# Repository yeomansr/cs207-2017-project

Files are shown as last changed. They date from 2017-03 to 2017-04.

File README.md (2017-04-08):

# Cyborg Headpiece (cs207-2017-project) [Version 1.3.3]
License:  [*Unlicense*](http://unlicense.org)

This is the repository for Richard Yeomans' CS 207 Project.

A cyborg headpiece, by my definition, is a piece of wearable technology affixed to the head of the wearer.  While I had originally intended to make the headpiece look as though it was integrated into the flesh of the wearer, I did not have enough time to finish it to this level of detail.

This class project has evolved a great deal from what I had originally intended.  At the beginning of the class, I did not really understand enough about what I would be able to do.  Now that the class is pretty well completed, this is the result of my work.

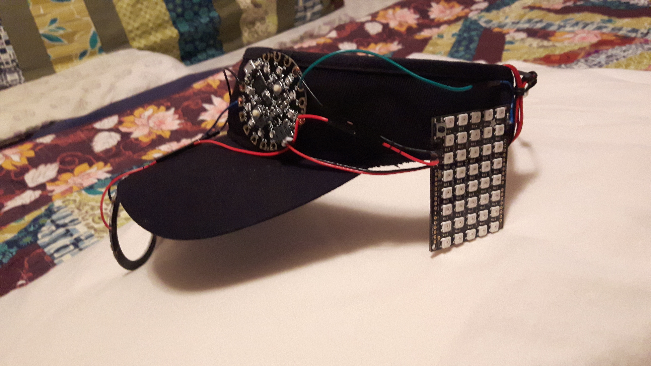
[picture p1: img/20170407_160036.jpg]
Cyborg Headpiece


[pic1]: https://github.com/yeomansr/cs207-2017-project/blob/master/img/20170407_160036.jpg "Cyborg Headpiece"

## Manifest
- **/doc** - technical documents (mostly PDF files)
- **/img** - image files (including Fritzing circuit diagrams)
- **/src** - source code file (.ino)
- **/LICENSE** - Unlicense file
- **/README.md** - this file

## Requirements and Materials
The following constitutes the materials I used in this project.  Many of these materials can be replaced with other similar materials as appropriate.
### Dependencies
- [add support for Adafruit to Arduino IDE](https://learn.adafruit.com/introducing-circuit-playground/arduino-1-dot-6-x-ide)
- [Adafruit NeoPixel Library](https://github.com/adafruit/Adafruit_NeoPixel) (not used, but helpful)

### Bill of Materials
- 1x [Adafruit Circuit Playground - Developer Edition](https://www.adafruit.com/products/3000)
- 1x [Adafruit NeoPixel Ring - 24 x 5050 RGB LED](https://www.adafruit.com/products/1586)
- 1x [Adafruit NeoPixel Shield for Arduino - 40 RGB LED Pixel Matrix](https://www.adafruit.com/products/1430)
- 1x [Adafruit USB cable - A/MicroB - 3ft](https://www.adafruit.com/product/592)
- 1x plain black visor
- 1x [Adafruit Premium Male/Male Jumper Wires - 40 x 6" (150mm)](https://www.adafruit.com/products/758)
- 1x [Adafruit Premium Female/Female Jumper Wires - 40 x 6"](https://www.adafruit.com/products/266)
- 1x [Adafruit JST-PH Battery Extension Cable - 500mm](https://www.adafruit.com/products/1131)
- 1x [Adafruit 3 x AAA Battery Holder with On/Off Switch and 2-Pin JST](https://www.adafruit.com/products/727)
- 3x Alkaline AAA batteries
- 1x [Adafruit Needle set - 3/9 sizes - 20 needles](https://www.adafruit.com/products/615)
- black thread
- clear nail polish
- black electrical tape
- wire cutters
- wire strippers

## Build Instructions
Ultimately, the components will be connected as per the following diagrams:

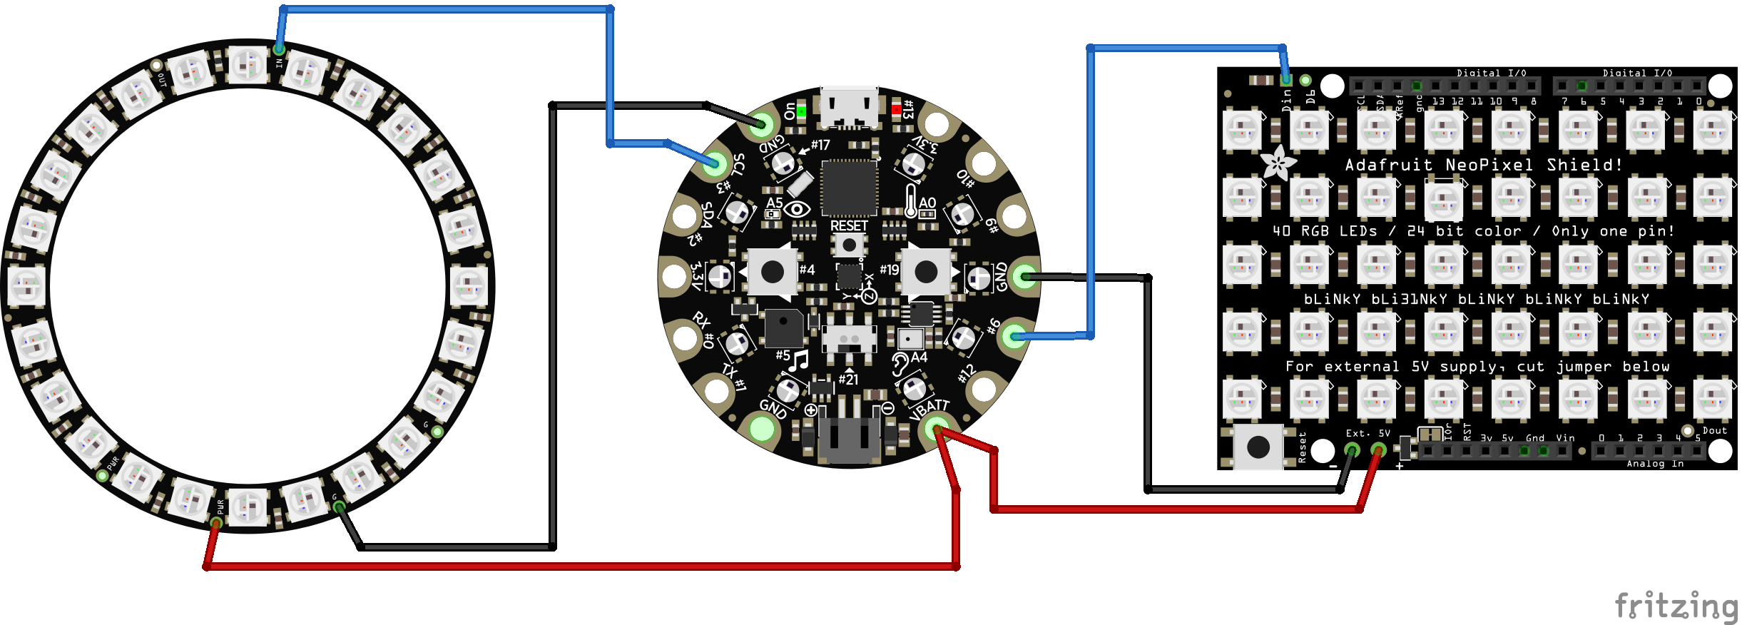
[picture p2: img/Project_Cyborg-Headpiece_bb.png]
Fritzing Diagram 1


[pic2]: https://github.com/yeomansr/cs207-2017-project/blob/master/img/Project_Cyborg-Headpiece_bb.png "Fritzing Diagram 1"

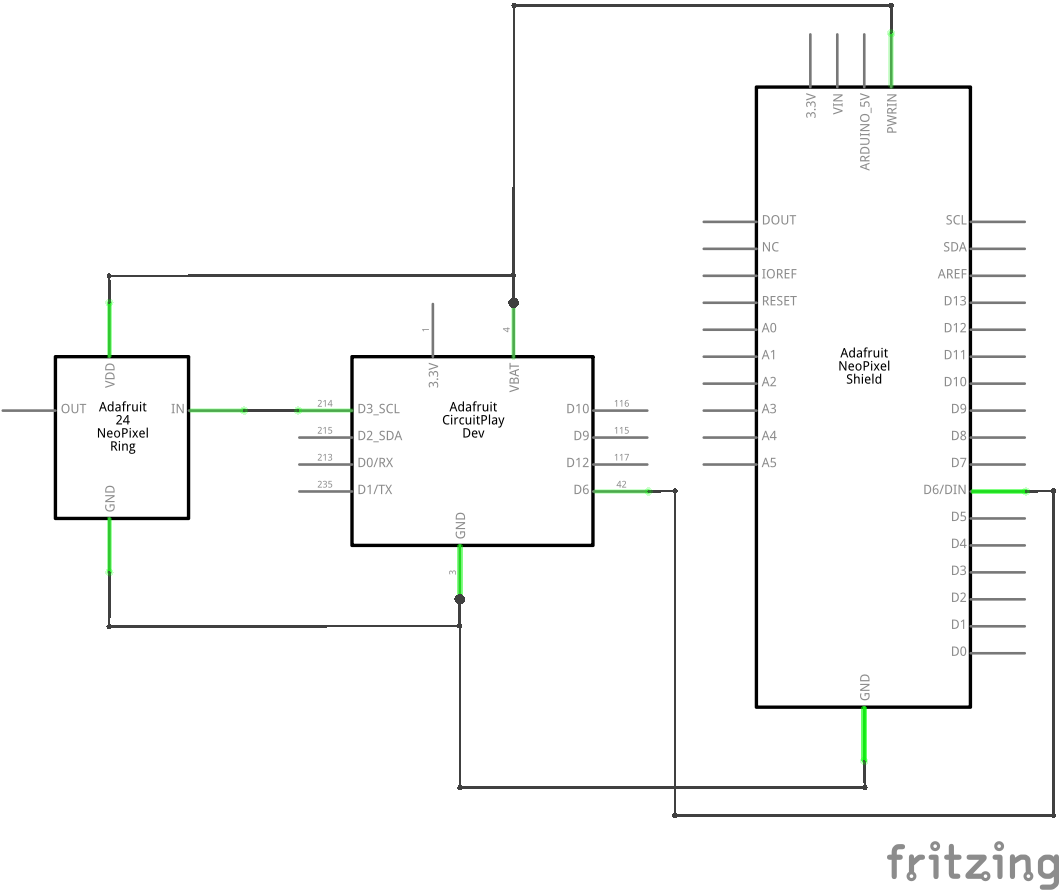
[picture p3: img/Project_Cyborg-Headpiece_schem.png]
Fritzing Diagram 2


[pic3]: https://github.com/yeomansr/cs207-2017-project/blob/master/img/Project_Cyborg-Headpiece_schem.png "Fritzing Diagram 2"

First, prepare the NeoPixel Shield and NeoPixel Ring by attaching some wires to the appropriate connectors:
1. Pull the Male/Male Jumper Wires apart, so that you are working with individual wires.
2. Take a black wire and cut it in half.
3. Strip about 3 cm off the wire end off both pieces (maintain the connector ends)
4. Wrap the stripped end of one of the wire pieces to the connector labeled *Ext.* on the NeoPixel Shield.  Continue wrapping it around several times.
5. Wrap the stripped end of one of the wire pieces to the connector labeled *GND* on the NeoPixel Ring.  Continue wrapping it around several times.
6. Place a dab of nail polish onto the front and back of both connectors, to seal the wires to the connectors.
7. Allow the nail polish to dry.
8. Trim any excess wire from the connectors, and make them neat.  Ensure you don't create any shorts while doing this.
9. Repeat steps 2 to 8, this time using a red wire, and connecting to *5V* on the NeoPixel Shield, and connecting to *PWR +5V* on the NeoPixel Ring.
10. Repeat steps 2 to 8, this time using a blue wire, and connecting to *Din* on the NeoPixel Shield, and connecting to *Data Input* on the NeoPixel Ring.

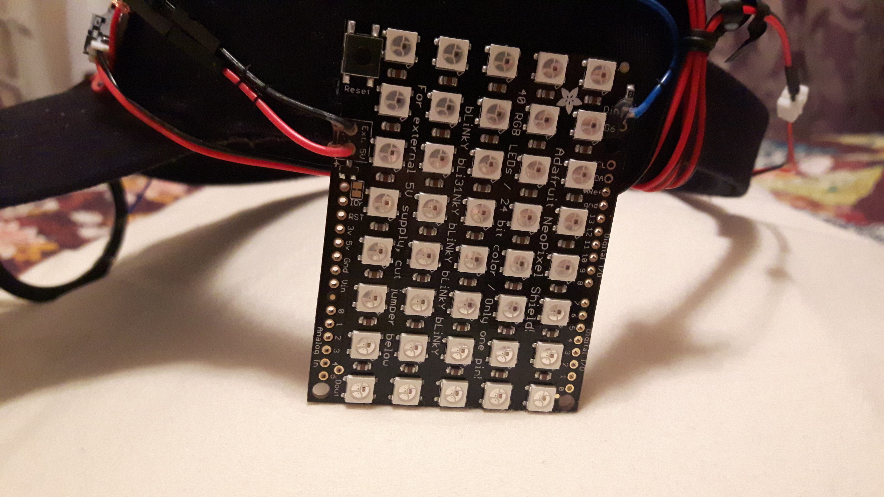
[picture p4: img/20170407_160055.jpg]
NeoPixel Shield


[pic4]: https://github.com/yeomansr/cs207-2017-project/blob/master/img/20170407_160055.jpg "NeoPixel Shield"

Attach the NeoPixel Shield and NeoPixel Ring to the visor using the black thread.  Simply sew the thread through any unused connector holes in the NeoPixel Shield to the side of the visor, allowing the end where the wires are not attached hang down.  When wearing the visor, the NeoPixel Shield should hang roughly over one of the wearer's ears.

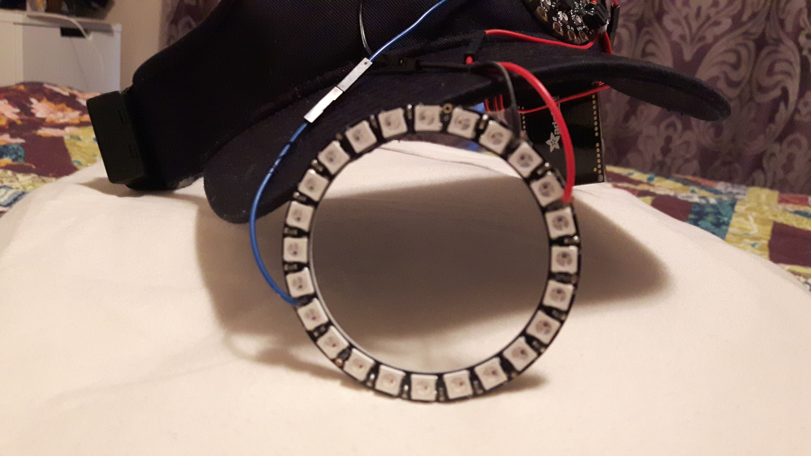
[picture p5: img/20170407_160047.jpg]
NeoPixel Ring


[pic5]: https://github.com/yeomansr/cs207-2017-project/blob/master/img/20170407_160047.jpg "NeoPixel Ring"

To attach the NeoPixel Ring, simply sew thread around the ring, between the NeoPixels to the end of the visor.  It will be loose to begin with, but as you sew more loops of thread to the visor, it will stabalize.  Ensure the wires are going up and over the visor.  Place the ring approximately in front of one of the wearer's eyes, sort of like a monocle.

Hold the Circuit Playground against the visor in an appropriate place between the NeoPixel Shield and NeoPixel Ring.  It isn't critical it be in any exact place, but you will want to hold it in place to identify how long the wires will need to be to connect to both the NeoPixel Shield and NeoPixel Ring.
1. Pull the Female/Female Jumper Wires apart, so that you are working with individual wires.
2. Repeat steps 2 to 8 above, this time using the Female/Female wire pieces.  Cut them to appropriate lengths based on the position of the components.  Make the wire pieces a little longer than you need, so that the wires are not too tight when connected.
  - For connections to the NeoPixel Shield: black wire to *GND*, red wire to *VBATT*, blue wire to *Pin #6*
  - For connections to the NeoPixel Ring: black wire to *GND*, red wire to *VBATT*, blue wire to *Pin #3*

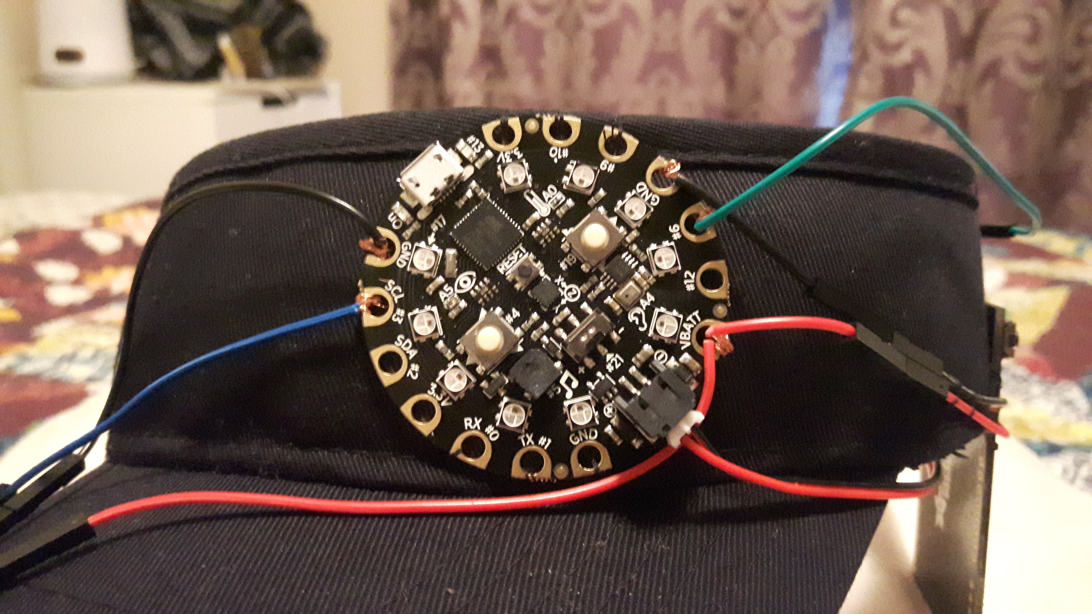
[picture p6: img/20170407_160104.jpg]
Circuit Playground


[pic6]: https://github.com/yeomansr/cs207-2017-project/blob/master/img/20170407_160104.jpg "Circuit Playground"

Sew the Circuit Playground to the visor in the same place you picked earlier.  Once it is secured to the visor, you may now connect the male and female ends of the wires to establish the connections between the Circuit Playground and the NeoPixel Shield and NeoPixel Ring.

Put batteries into the Battery Holder.  Find an appropriate place to attach the Battery Holder; use the electrical tape to attach it.  If the connector for the Battery Holder is too far from the Circuit Playground to connect, make use of the Battery Extension Cable, as I did.

Use black thread as appropriate to hold the wires nicely to the visor.

## Firmware Installation
In order to upload the code to the Circuit Playground, you will need to first install the Arduino IDE software.  Follow the instructions on Adafruit's website: *Arduino 1.6.x IDE* in the references.  Don't forget to add the *Adafruit Board Support* package, further down on the page.

Connect the Circuit Playground using the USB cable.  Load the code *sketch_project.ino* that can be found in the *src* directory.

## Usage
The Battery Holder has a power switch on it; use this switch to turn on or off the headpiece.

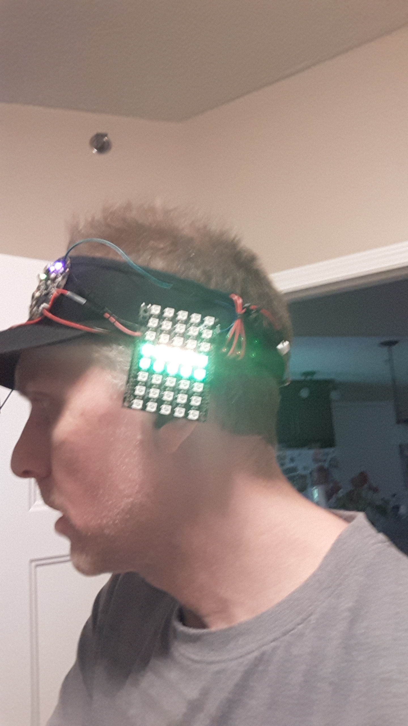
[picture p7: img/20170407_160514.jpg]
Sound Reactor


[pic7]: https://github.com/yeomansr/cs207-2017-project/blob/master/img/20170407_160514.jpg "Sound Reactor"

The NeoPixel Shield responds to sounds.  Talk or otherwise make some noises and you will see the NeoPixel Shield light up.

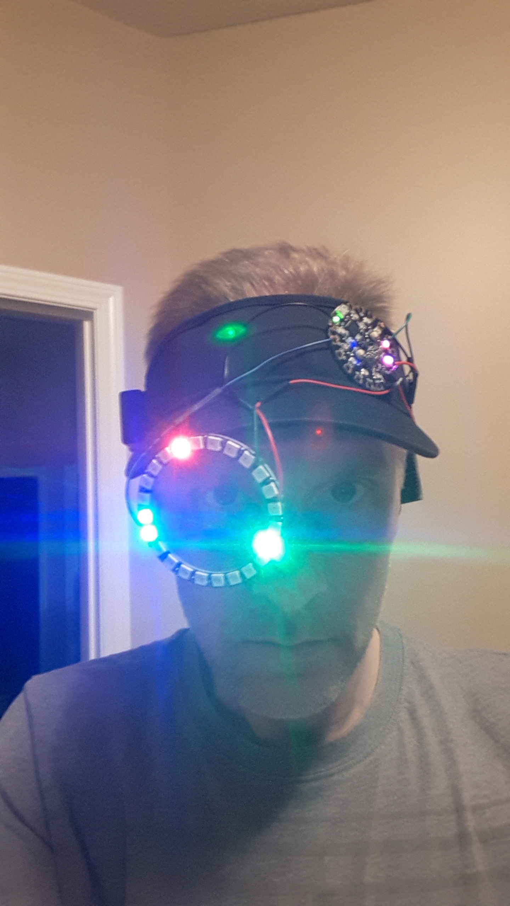
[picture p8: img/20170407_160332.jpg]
Orientation Reactor


[pic8]: https://github.com/yeomansr/cs207-2017-project/blob/master/img/20170407_160332.jpg "Orientation Reactor"

The NeoPixel Ring responds to the visor's orientation.  The 3 dots will rotate around the ring based on the X, Y, and Z orientations of the Circuit Playground.  Move it around to see the effects.

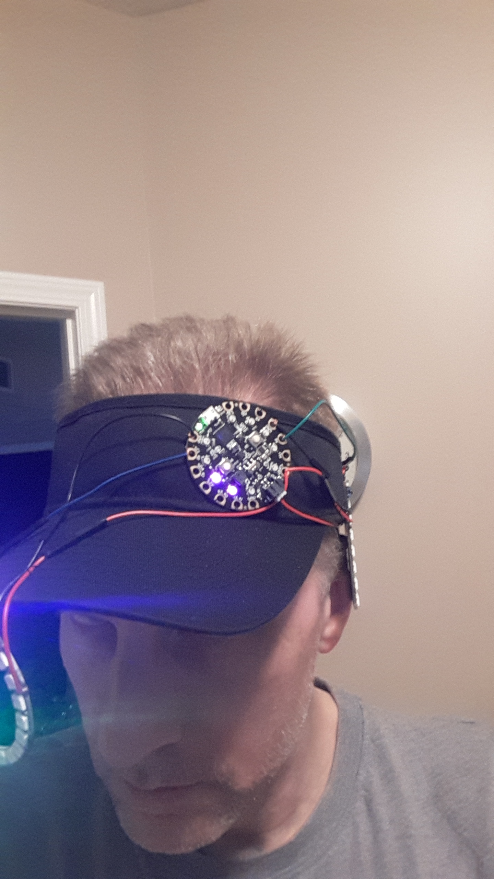
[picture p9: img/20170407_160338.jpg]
Basic Operation


[pic9]: https://github.com/yeomansr/cs207-2017-project/blob/master/img/20170407_160338.jpg "Basic Operation"

The Circuit Playground has some NeoPixels on it as well.  The dot will go around it to indicate that there is stuff going on.  Both buttons can be pressed and will change the behavior of the Circuit Playground dot.  Furthermore, the switch on the Circuit Playground will freeze all responses on all components when switched.

## Team
The project team consists of:
- [Richard Yeomans](mailto:yeomansr@uregina.ca)

It's a small team.

## Acknowledgements
### Credits
- Robin Canham - her assistance and support was invaluable
- Trevor Tomesh - CS 207 class instructor, provided insight and assistance all over the place

### References
- *Arduino 1.6.x IDE | Introducing Circuit Playground | Adafruit Learning System*.  (2017).  *Learn.adafruit.com*.  Retrieved 8 April 2017, from [https://learn.adafruit.com/introducing-circuit-playground/arduino-1-dot-6-x-ide](https://learn.adafruit.com/introducing-circuit-playground/arduino-1-dot-6-x-ide)
- *adafruit/Fritzing-Library*.  (2017).  *GitHub*.  Retrieved 8 April 2017, from [https://github.com/adafruit/Fritzing-Library](https://github.com/adafruit/Fritzing-Library)
- *Downloads | Introducing Circuit Playground | Adafruit Learning System*.  (2017).  *Learn.adafruit.com*.  Retrieved 19 March 2017, from [https://learn.adafruit.com/introducing-circuit-playground/downloads](https://learn.adafruit.com/introducing-circuit-playground/downloads)
- *Mastering Markdown · GitHub Guides*.  (2017).  *Guides.github.com*.  Retrieved 5 February 2017, from [https://guides.github.com/features/mastering-markdown/](https://guides.github.com/features/mastering-markdown/)
- Stern, B. & Burgess, P.  (2017).  *Cyberpunk Spikes | Make:. Make: DIY Projects and Ideas for Makers*.  Retrieved 5 February 2017, from [http://makezine.com/projects/make-42/cyberpunk-spikes/](http://makezine.com/projects/make-42/cyberpunk-spikes/)
- *The Magic of NeoPixels | Adafruit NeoPixel Überguide | Adafruit Learning System*.  (2017).  *Learn.adafruit.com*.  Retrieved 25 March 2017, from [https://learn.adafruit.com/adafruit-neopixel-uberguide/overview](https://learn.adafruit.com/adafruit-neopixel-uberguide/overview)
- Tomesh, T.  (2017).  *trevortomesh/OSHRepo*.  *GitHub*.  Retrieved 5 February 2017, from [https://github.com/trevortomesh/OSHRepo](https://github.com/trevortomesh/OSHRepo)

## Version History
version 1.3.3
- fixing formatting errors in README

version 1.3.2
- added pictures and diagrams

version 1.3.1
- fixing formatting errors in README

version 1.3.0
- updated description
- updated Manifest
- updated Requirements and Materials
- added Build Instructions
- added Firmware Installation
- added Usage
- added reference to Arduino 1.6.x IDE
- added reference to Adafruit Fritzing Library

version 1.2.0
- added reference to NeoPixel guide

version 1.1.5
- fixing formatting errors in README

version 1.1.4
- fixing formatting errors in README

version 1.1.3
- added reference to Adafruit downloads for Circuit Playground

version 1.1.2
- added manufacturer information to materials

version 1.1.1
- fixing formatting errors in README

version 1.1.0
- updates to bill of materials

version 1.0.3
- added important reference

version 1.0.2
- fixing formatting errors in README

version 1.0.1
- fixing formatting errors in README

version 1.0.0
- starting project

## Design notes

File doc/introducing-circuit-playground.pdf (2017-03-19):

### Introducing Circuit Playground

Created by lady ada

Last updated on 2017-02-08 04:37:44 PM UTC

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
## Guide Contents

Guide Contents Overview Pinouts GPIO + Capacitive Touch Pads NeoPixels Pushbuttons Slide Switch Light Sensor Temperature Sensor Speaker Buzzer Microphone Audio Sensor Triple-Axis Accelerometer Windows Driver Installation Manual Driver Installation Arduino 1.6.x IDE Super Easy Installation (Recommended)

Add the Adafruit Board Support package!
Manage Board Support

### All-in-one Installation (not recommended!) Manual Installation (super advanced!) HELP! Libraries Installing Via Library Manager Download Adafruit_CircuitPlayground 'Manually' Run the Demo

Select the Circuit Playground Board
Select the matching Port
Load the Demo Program
Compile/Verify the Demo
Upload Demo

### Downloads Windows Driver Software

© Adafruit Industries | https://learn.adafruit.com/introducing-circuit-playground | Page 2 of 37

35
35
35
36

### Source Datasheets Schematic Fabrication Print

© Adafruit Industries | https://learn.adafruit.com/introducing-circuit-playground | Page 3 of 37

# Overview

Would you like to learn electronics, with an all-in-one board that has sensors and LEDs built in? Circuit Playground is here, and it's the best way to practice programming on real hardware. No soldering or sewing required!

Circuit Playground features an ATmega32u4 micro-processor, just like our popular Flora. It also is round and has alligator-clip pads around it. You can power it from USB, a AAA battery pack (http://adafru.it/727), or Lipoly (for advanced users). Program your code (https://www.adafruit.com/products/727) into it, then take it on the go.

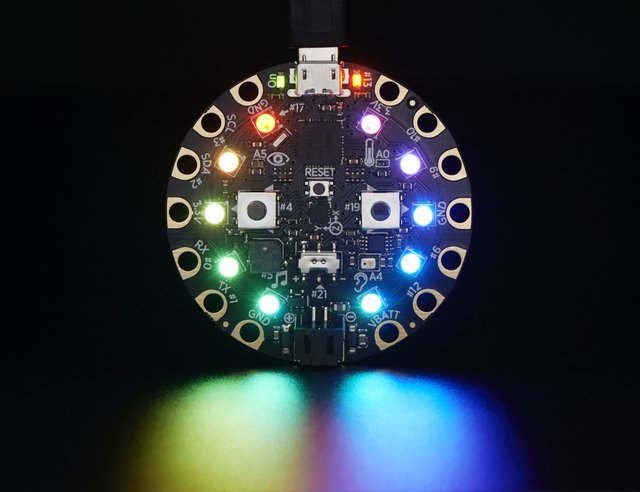
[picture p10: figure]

ATmega32u4 Processor, running at 3.3V and 8MHz
MicroUSB port for programming and debugging with Arduino IDE
USB port can act like serial port, keyboard, mouse, joystick or MIDI
© Adafruit Industries | https://learn.adafruit.com/introducing-circuit-playground | Page 4 of 37

Circuit Playground has built-in USB support. Built in USB means you plug it in to program it, it just shows up - all you need is a Micro-B USB cable, no additional purchases are needed! With the new 1.6.4+ Arduino IDE, it takes only a few seconds to add
support (http://adafru.it/nb4). The Circuit Playground has USB HID support, so it can act like a mouse or keyboard to attach directly to computers.

Here's some of the great goodies baked in:

10 x mini NeoPixels, each one can display any rainbow color
1 x Motion sensor (LIS3DH triple-axis accelerometer with tap detection, free-fall detection)
1 x Temperature sensor (thermistor)
1 x Light sensor (phototransistor)
1 x Sound sensor (MEMS microphone) 1 x Mini speaker (magnetic buzzer)
2 x Push buttons, left and right
1 x Slide switch
8 x alligator-clip friendly input/output pins
© Adafruit Industries | https://learn.adafruit.com/introducing-circuit-playground | Page 5 of 37

Includes I2C, UART, and 4 pins that can do analog inputs/PWM output All 8 pads can act as capacitive touch inputs
Green "ON" LED so you know its powered
Red "#13" LED for basic blinking
Reset button

We've started out with aDeveloper Edition of Circuit Playground. This version is designed for people who have a little experience with Arduino already, who want to help build & document projects. There might be minor hardware or software bugs. Once we feel like the design is really solid we'll revise/re-release it into a universal edition for anyone to use!

© Adafruit Industries | https://learn.adafruit.com/introducing-circuit-playground | Page 6 of 37

# Pinouts

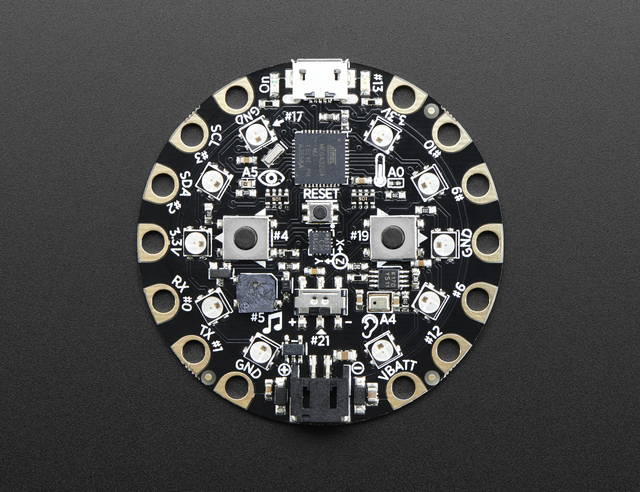
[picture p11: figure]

Circuit Playground is chock-full of blinkies, sensors and electronic goodies. Since there's a lot going on, we're going to look at each piece one by one and talk about what it is and how to use it. This is a technically-oriented description for the Developer Edition and the people who are planning on writing code for Circuit Playground

# GPIO + Capacitive Touch Pads

© Adafruit Industries | https://learn.adafruit.com/introducing-circuit-playground | Page 7 of 37

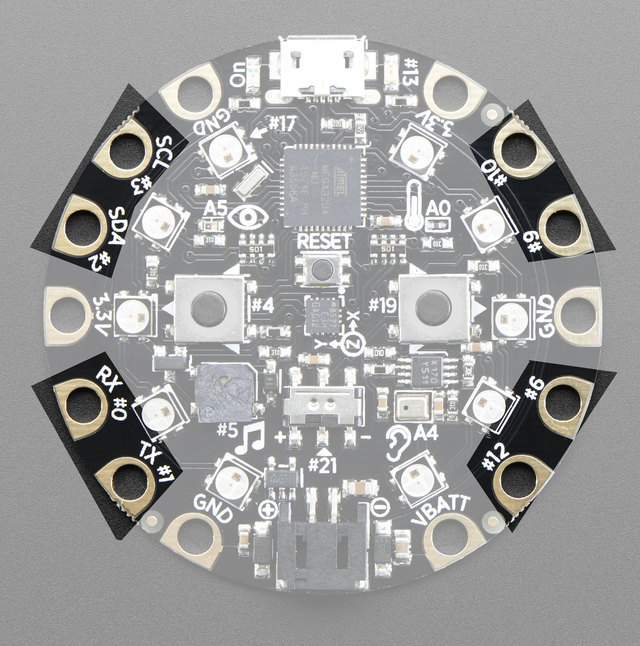
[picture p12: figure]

All 8 non-power pads around the circuit playground have the ability to act as capacitive touch pads. Each pad has a 1Mohm resistor between it and digital pin #30. You can toggle this pin to control whether the resistor is a pullup or pulldown or floating. Note that this means that all the pads have a 2Mohm resistance between them.

You can also of course just use those pads for GPIO, we expose the hardware Serial (TX + RX), hardware I2C (SDA + SCL) and 4 gpio pins that can also do analog readings. They are the same exact pins as those on the Flora

© Adafruit Industries | https://learn.adafruit.com/introducing-circuit-playground | Page 8 of 37

# NeoPixels

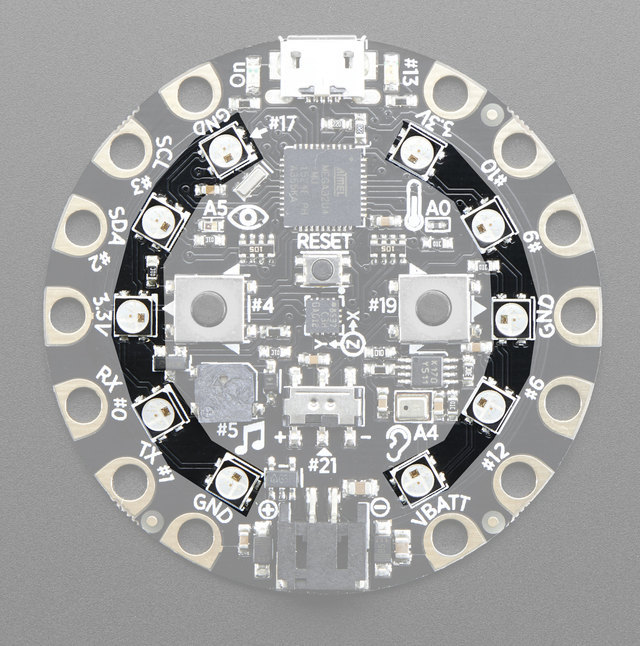
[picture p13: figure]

Each Circuit Playground comes with 10 'NeoPixels' (technically, SK6812-3535 chips). These are connected to digital pin #17 and are powered by the 3.3V regulator. This is technically undervolting but we test them at this voltage and they work fine, if slightly tinted

# Pushbuttons

© Adafruit Industries | https://learn.adafruit.com/introducing-circuit-playground | Page 9 of 37

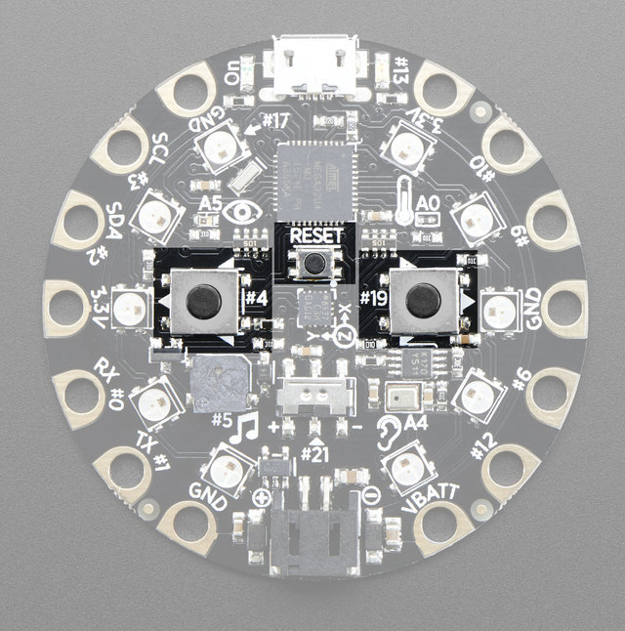
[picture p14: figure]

There are three tactile pushbutton switches. One is the Reset button. Press this button once to reset, double-click to enter the bootloader manually.

The other two buttons are the Left and Right buttons, connected to digital#4 (Left) and #19 (Right) each. These have pull-down resistors installed so are, by default, LOW and when pressed read HIGH. This is to make if-then logic a little easier to read for beginners

# Slide Switch

© Adafruit Industries | https://learn.adafruit.com/introducing-circuit-playground | Page 10 of 37

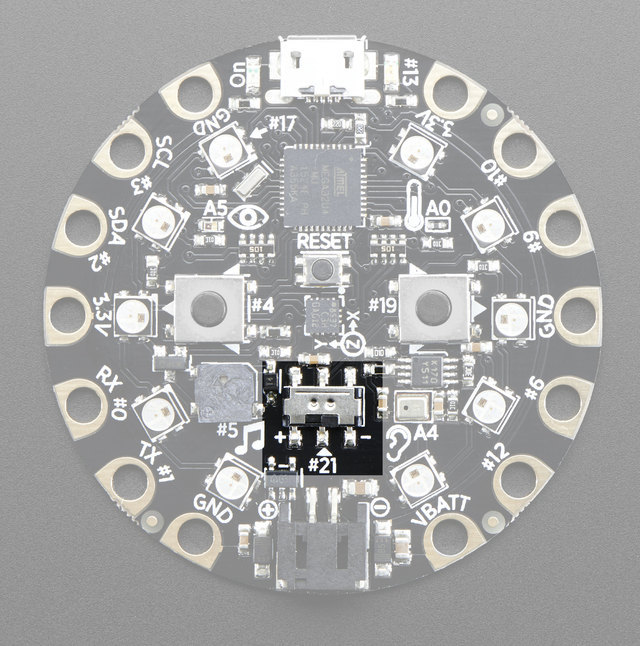
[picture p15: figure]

There is a single slide switch near the center of the Circuit Playground. It is connected to digital #21 and will read LOW when slid to the left, and HIGH when in the right hand position

# Light Sensor

© Adafruit Industries | https://learn.adafruit.com/introducing-circuit-playground | Page 11 of 37

There is an analog light sensor,part number ALS-PT19 (http://adafru.it/tC2), in the top left part of the board. This can be used to detect ambient light, with similar spectral response to the human eye.

This sensor is connect to analog pin #A5 and will read between 0 and 1023 with higher values corresponding to higher light levels. A reading of about 300 is common for most indoor light levels.

# Temperature Sensor

© Adafruit Industries | https://learn.adafruit.com/introducing-circuit-playground | Page 12 of 37

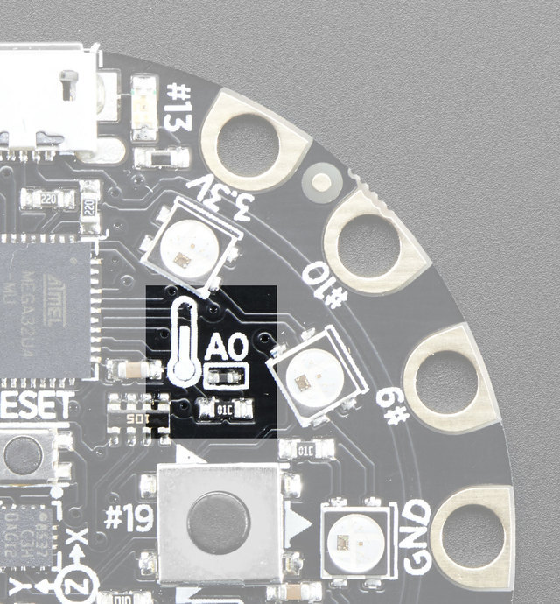
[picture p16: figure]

There is an NTC thermistor (Murata NCP15XH103F03RC) that we use for temperature sensing. While it isn't an all-in-one temperature sensor, with linear output, it's easy to calculate the temperature based on the analog voltage on analog pin #A0. There's a 10K resistor connected to it as a pull down.

# Speaker Buzzer

© Adafruit Industries | https://learn.adafruit.com/introducing-circuit-playground | Page 13 of 37

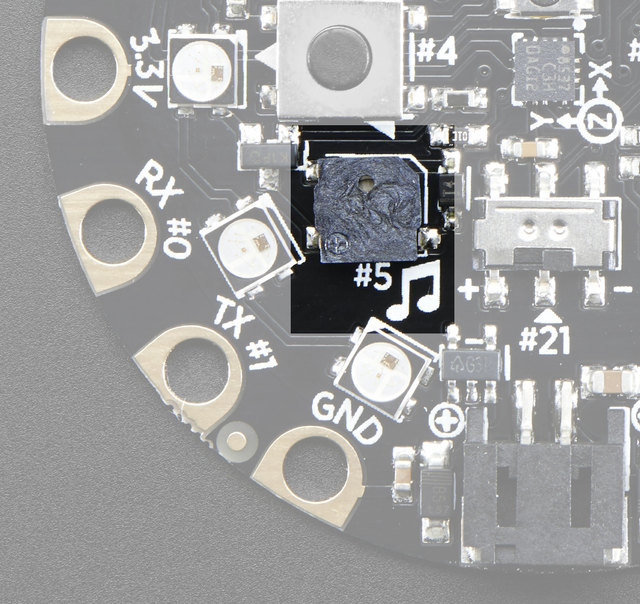
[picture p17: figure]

You can make your circuit playground sing with the built in buzzer. This is a miniature magnetic speaker connected to digital pin #5 with a transistor driver. You can use PWM at varying frequencies to make basic tones.

# Microphone Audio Sensor

© Adafruit Industries | https://learn.adafruit.com/introducing-circuit-playground | Page 14 of 37

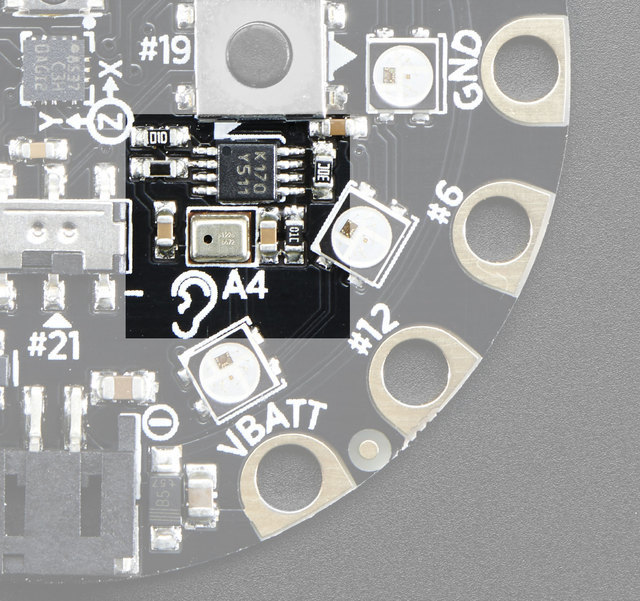
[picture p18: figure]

A MEMS microphone can be used to detect audio levels and even perform basic FFT functions. You can read the analog voltage corresponding to the audio on analog pin #A4. Note that this is the raw analog audio waveform! When it's silent there will be a reading of ~330 and when loud the audio will read between 0 and 800 or so. Averaging and smoothing must be done to convert this to sound-pressure-level.

# Triple-Axis Accelerometer

© Adafruit Industries | https://learn.adafruit.com/introducing-circuit-playground | Page 15 of 37

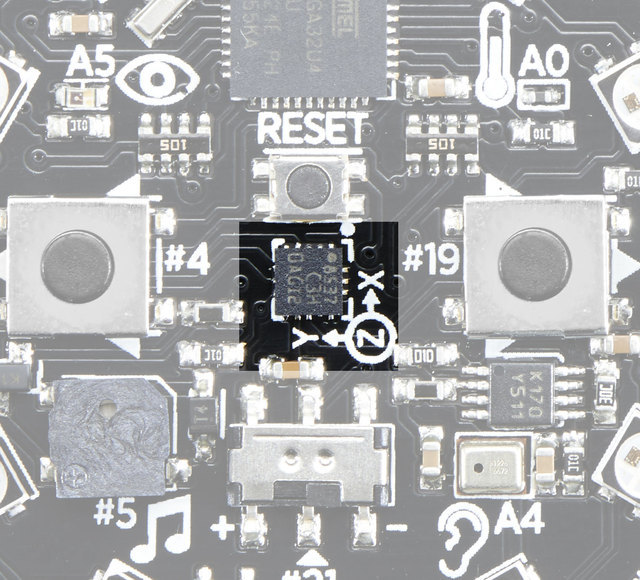
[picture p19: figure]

A LIS3DH 3-axis XYZ accelerometer is in the dead center of the board and you can use it to detect tilt, gravity, motion, as well as 'tap' and 'double tap' strikes on the board. The LIS3DH is connected to the hardware SPI pins (to leave the I2C pins free) and has the CS pin on digital pin #8 and an optional interrupt output on digital pin#7 (also known as IRQ #4)

© Adafruit Industries | https://learn.adafruit.com/introducing-circuit-playground | Page 16 of 37

# Windows Driver Installation

Mac and Linux do not require drivers, only Windows folks need to do this step

Before you plug in your board, you'll need to possibly install a driver!

Click below to download our Driver Installer

Download Adafruit Windows Driver Installer (https://github.com/adafruit/Adafruit_Windows_Drivers/releases/download/1.0.0.0/adafruit_drivers.exe)
http://adafru.it/mai

Download and run the installer

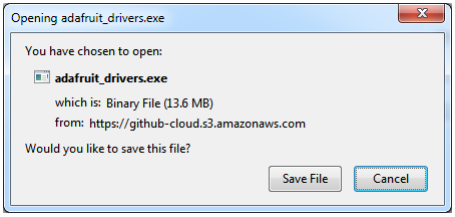
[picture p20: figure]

Run the installer! Since we bundle the SiLabs and FTDI drivers as well, you'll need to click through the license

© Adafruit Industries | https://learn.adafruit.com/introducing-circuit-playground | Page 17 of 37

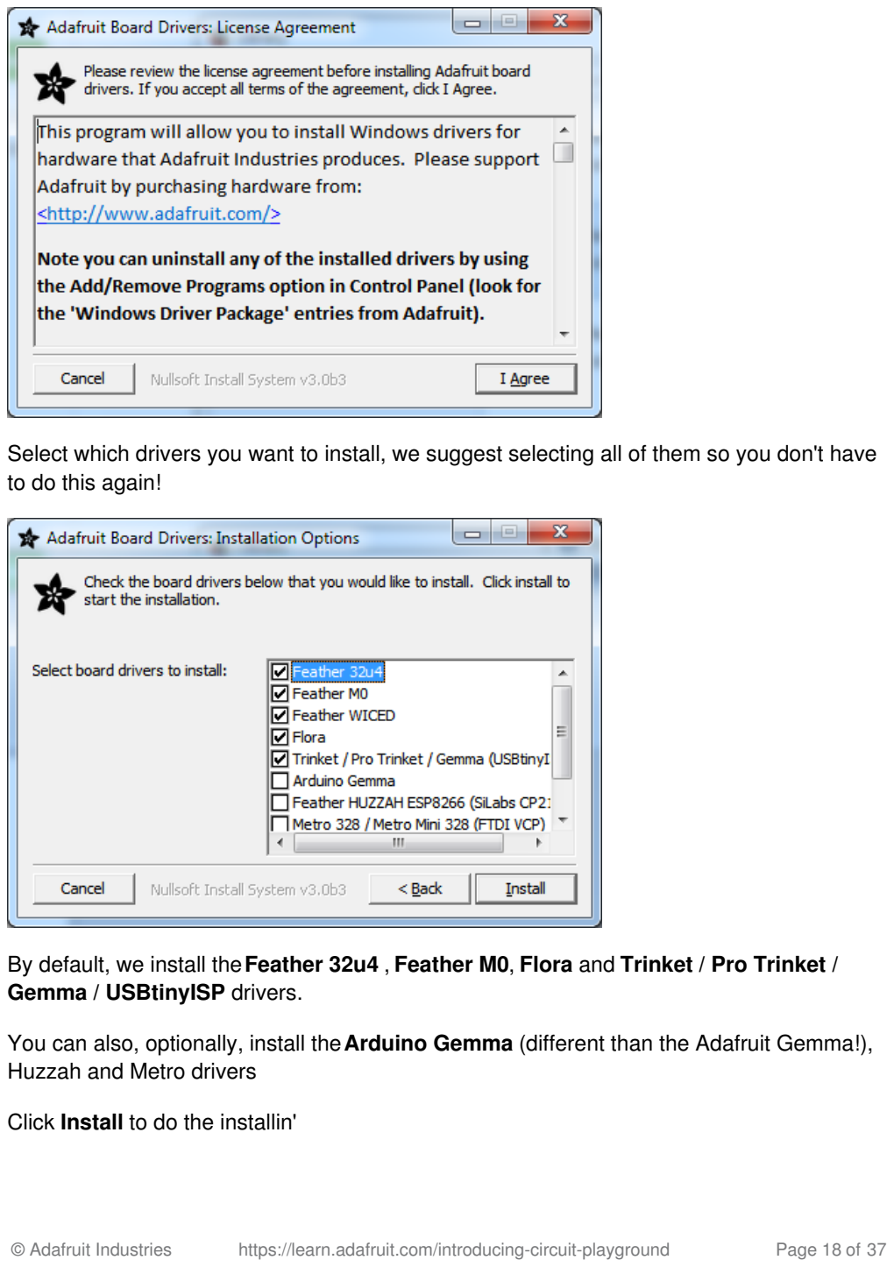
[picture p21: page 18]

Select which drivers you want to install, we suggest selecting all of them so you don't have to do this again!

By default, we install theFeather 32u4 , Feather M0, Flora and Trinket / Pro Trinket / Gemma / USBtinyISP drivers.

You can also, optionally, install theArduino Gemma (different than the Adafruit Gemma!), Huzzah and Metro drivers

Click Install to do the installin'

© Adafruit Industries | https://learn.adafruit.com/introducing-circuit-playground | Page 18 of 37

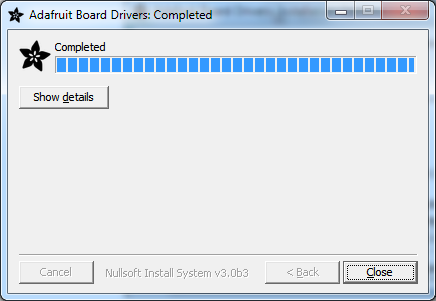
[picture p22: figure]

# Manual Driver Installation

If windows needs the driver files (inf/cat) for some reason you can get all the drivers in a zip by clicking below:

Adafruit Windows Drivers (https://github.com/adafruit/Adafruit_Windows_Drivers/archive/master.zip)
http://adafru.it/rEY

And point windows to theDrivers folder when it asks for the driver location

© Adafruit Industries | https://learn.adafruit.com/introducing-circuit-playground | Page 19 of 37

# Arduino 1.6.x IDE

The Arduino IDE version 1.6.x is the latest version of Arduino and recommended for most users. Follow the steps on this page to learn how to install a version of the Arduino 1.6.x IDE with support for Adafruit's boards.

# Super Easy Installation (Recommended)

With the Arduino IDE version 1.6.4 and greater you can now add 3rd party boards directly from the stock IDE! The first thing you will need to do is to download the latest release of the Arduino IDE. You will need to be using version 1.6.4 or higher:

Latest Arduino IDE Download (http://www.arduino.cc/en/Main/Software)
http://adafru.it/f1P

After you have downloaded and installed the latest version (remember itmust be 1.6.4 or higher), you will need to start the IDE and navigate to the Preferences menu. You can access it from the File menu in Windows or Linux, or the Arduino menu on OS X.

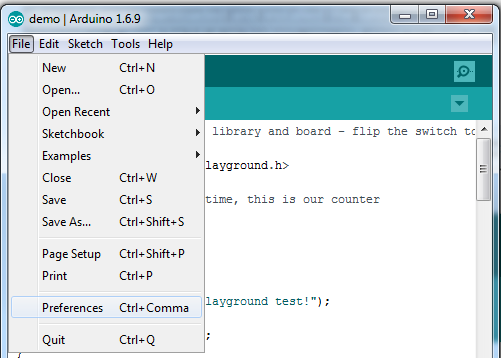
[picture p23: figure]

A dialog will pop up just like the one shown below.

© Adafruit Industries | https://learn.adafruit.com/introducing-circuit-playground | Page 20 of 37

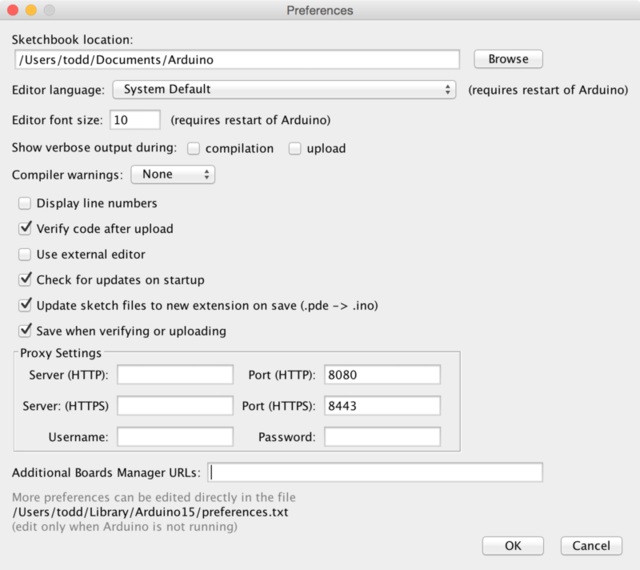
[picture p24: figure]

We will be adding a URL to the newAdditional Boards Manager URLs option. The list of URLs is comma separated, and you will only have to add each URL once.New Adafruit boards and updates to existing boards will automatically be picked up by the Board Manager each time it is opened. The URLs point to index files that the Board Manager uses to build the list of available & installed boards.

To find the most up to date list of URLs you can add, you can visit the list ofthird party board URLs on the Arduino IDE wiki (http://adafru.it/f7U). We will only need to add one (https://github.com/arduino/Arduino/wiki/Unofficial-list-of-3rd-party-boards-support-urls) URL to the IDE in this example, but you can add multiple URLS by separating them with commas. Copy and paste the link below into the Additional Boards Manager URLs option in the Arduino IDE preferences.

If you don't see the Additional Boards Manager URLs box, make sure you downloaded the Arduino IDE from arduino.cc! Older versions and derivatives of the IDE may not have it

© Adafruit Industries | https://learn.adafruit.com/introducing-circuit-playground | Page 21 of 37

## Add the Adafruit Board Support package!

Paste

https://adafruit.github.io/arduino-board-index/package_adafruit_index.json Into the "Additional Board Managers URLS" box

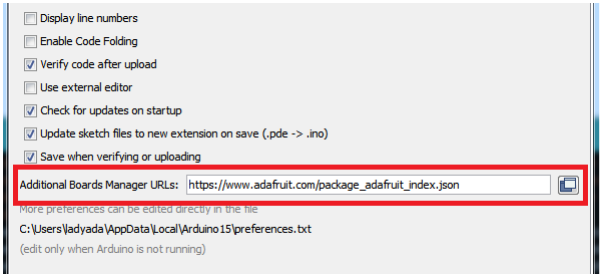
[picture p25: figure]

Click OK to save the new preference settings. Next we will look at installing boards with the Board Manager.

## Manage Board Support

Adding the link to the Adafruit board support package does not actually install anything, it only tells the Arduino IDE where to find the software.

Now that you have added the appropriate URLs to the Arduino IDE preferences, you can open the Boards Manager by navigating to theTools->Board menu.

Once the Board Manager opens, click on the category drop down menu on the top left hand side of the window and select Contributed. You will then be able to select and install the boards supplied by the URLs added to the prefrences. In the example below, we are installing support for Adafruit AVR Boards, but the same applies to all boards installed with the Board Manager.

© Adafruit Industries | https://learn.adafruit.com/introducing-circuit-playground | Page 22 of 37

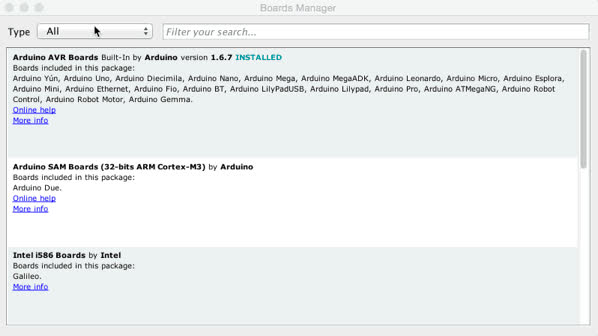
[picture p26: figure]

Next, quit and reopen the Arduino IDEto ensure that all of the boards are properly installed. You should now be able to see the new boards listed in the Tools->Board menu.

Finally follow the steps below for your platform to finish the installation - basically installing drivers and permissions management

Windows Setup (http://adafru.it/jAa)
Mac OSX Setup (http://adafru.it/mak)
Linux Setup (http://adafru.it/iOE)

Also check out the troubleshooting section (http://adafru.it/mal) for some advice on common errors. Have fun using Adafruit's boards!

# All-in-one Installation (not recommended!)

If you have trouble using the super easy installation method above another way to install support for Adafruit's boards is with the following preconfigured Arduino IDE downloads. It isn't recommended because you wont have the latest IDE!

Just grab the right file for your platform and use it like the normal Arduino IDE. Adafruit's boards like Trinket, Pro Trinket, Gemma, and Flora are configured to show up in the board list automatically

Arduino 1.6.4 with Adafruit Boards for Windows (https://s3.amazonaws.com/adafruit-download/adafruit-arduino-1.6.4-windows.zip)
http://adafru.it/f83
© Adafruit Industries | https://learn.adafruit.com/introducing-circuit-playground | Page 23 of 37

Arduino 1.6.4 with Adafruit Boards for Mac OSX (10.7+) (https://s3.amazonaws.com/adafruit-download/adafruit-arduino-1.6.4-macosx.zip) http://adafru.it/f84
Arduino 1.6.4 with Adafruit Boards for Linux (32-bit) (https://s3.amazonaws.com/adafruit-download/adafruit-arduino-1.6.4-linux32.tar.xz) http://adafru.it/f85
Arduino 1.6.4 with Adafruit Boards for Linux (64-bit) (https://s3.amazonaws.com/adafruit-download/adafruit-arduino-1.6.4-linux64.tar.xz)
http://adafru.it/f86

Once you've downloaded and installed the IDE follow the steps below for your platform to finish the installation:

Windows Setup (http://adafru.it/jAa)
Mac OSX Setup (http://adafru.it/mak)
Linux Setup (http://adafru.it/iOE)

Also check out the troubleshooting section (http://adafru.it/mal) for some advice on common errors. Have fun using Adafruit's boards!

# Manual Installation (super advanced!)

If you have your own version of the Arduino IDE or would like to install the Adafruit boards yourself then follow the steps below. However it is highly recommended that most users stick to the initial methods

With the 1.6.x version of the Arduino IDE the process of adding support for new boards is much simpler than previous versions. First start by downloading a version of the Arduino 1.6.x IDE and installing it as normal. Note that these instructions are only tested to work against the Arduino 1.6.4 IDE, earlier or later versions may or may not work!

Once you've installed the stock Arduino IDE download and unzip the following file which contains Adafruit's board definitions (https://github.com/adafruit/Adafruit_Arduino_Boards) (http://adafru.it/eTY):

Adafruit Board Definitions (https://github.com/adafruit/Adafruit_Arduino_Boards/archive/master.zip)
http://adafru.it/eTZ

Unzip the file and navigate inside theAdafruit_Arduino_Boards folder to find a hardware subfolder with a small hiearchy of files, and adrivers folder with Flora drivers specific to Windows.

Next find your installed Arduino IDE's hardware subfolder. For Windows and Linux the hardware subfolder should be directly beneath the folder where Arduino's IDE was installed.

For Mac OSX the folder is hidden inside the application bundle. Right click on the Arduino

© Adafruit Industries | https://learn.adafruit.com/introducing-circuit-playground | Page 24 of 37

application and click 'Show Package Contents', then navigate to theContent -> Java -> Hardware folder to find the hardware subfolder.

Once you've found Arduino's hardware subfolder carefully merge in the contents of the hardware folder from Adafruit's board definitions, being sure to overwrite any file that conflicts (only avrdude.conf should conflict). When you're done the Arduino hardware folder should have the following hiearchy:

hardware
adafruit
avr
The contents of the hardware/adafruit/avr folder from Adafruit's board definitions. There will be a boards.txt, platform.txt
and variants subfolder.
arduino
No changes to this hiearchy, it is exactly as provided by the Arduino IDE. tools
avr
etc
avrdude.conf - This version of avrdude.conf should be from Adafruit's board definitions and completely overwrites the version provided by the Arduino IDE.
... all other files as provided by the Arduino IDE.
... all other files as provided by the Arduino IDE.

Finally on Windows only, copy the contents of the drivers folder from the board definitions download into the Arduino IDE's drivers folder (it's a sibling of the hardware folder you found earlier).

That's all you need to do to manually install Adafruit's boards with the 1.6.x version of Arduino! Now follow the steps below for your platform to finish the installation:

Windows Setup (http://adafru.it/jAa)
Mac OSX Setup (http://adafru.it/mak)
Linux Setup (http://adafru.it/iOE)

Also check out the troubleshooting section (http://adafru.it/mal) for some advice on common errors. Have fun using Adafruit's boards!

© Adafruit Industries | https://learn.adafruit.com/introducing-circuit-playground | Page 25 of 37

# HELP!

I just plugged it in and I can't seem to connect to my Circuit Playground with Arduino!

99% of initial problems with circuit playground are due to havingcharge USB cables instead of sync cables. Do not use a cable you've only used for charging a phone. Make sure its a cable that can pass data as well as power. Lately, there's been a lot of products shipped with charging only cables and it's very confusing because the Circuit Playground lights up but does not show up in the Arduino IDE!

So, please, try multiple USB cables, and if you find a charge-only cable, cut it in half and throw it away so you will not make the mistake again!

Ack! I "did something" and now when I plug in the Circuit Playground it doesn't show up as a device anymore so I cant upload to it or fix it...

No problem! You can 'repair' a bad code upload easily. Note that this can happen if you set a watchdog timer or sleep mode that stops USB, or any sketch that 'crashes' your Circuit Playground

1. Turn on verbose upload in the Arduino IDE preferences
2. Plug in Circuit Playground, it won't show up as a COM/serial port that's ok
3. Open up the Blink example (Examples->Basics->Blink)
4. Select the correct board in the Tools menu, e.g.Circuit Playground (make sure you select the correct board)
5. Compile it (make sure that works)
6. Click Upload to attempt to upload the code
7. The IDE will print out a bunch of COM Ports as it tries to upload.During this time, double click the reset button, you'll see the red pulsing LED that tells you its now in bootloading mode
8. The Cplay will show up as the Bootloader COM/Serial port
9. The IDE should see the bootloader COM/Serial port and upload properly
© Adafruit Industries | https://learn.adafruit.com/introducing-circuit-playground | Page 26 of 37

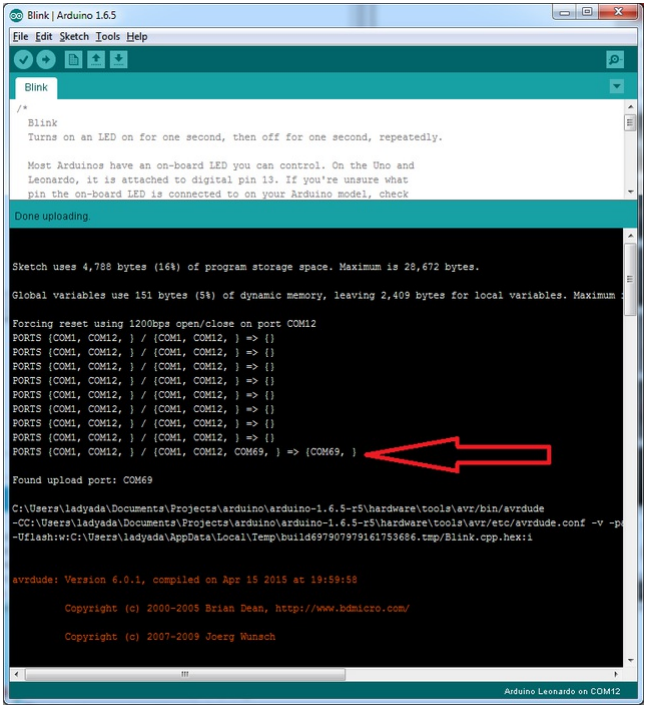
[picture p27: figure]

I can't get the Circuit Playground USB device to show up - I get "USB Device Malfunctioning" errors!

This seems to happen when people select the wrong board from the Arduino Boards menu. Make sure you select Circuit Playground! Do not use anything else, do not use the 32u4 breakout board line.

Use the 'repair' technique above to fix it.

© Adafruit Industries | https://learn.adafruit.com/introducing-circuit-playground | Page 27 of 37

© Adafruit Industries | https://learn.adafruit.com/introducing-circuit-playground | Page 28 of 37

# Libraries

We wrapped up everything you need to run Arduino code on your Circuit Playground is wrapped up into a tidy library that integrates all the sensing and lighting.

# Installing Via Library Manager

The Circuit Playground library is available on theAdafruit GitHub
website (http://adafru.it/naF). The library is installed in versions (https://github.com/adafruit/Adafruit_CircuitPlayground) of the Arduino IDE greater than 1.6.7 as follows:

In the menu click "Sketch", then "Include Library"
At the top, click "Manage Libraries. . ."
Type "Circuit Playground" in the search box. You should see Adafruit Circuit Playground listed.

# Download Adafruit_CircuitPlayground 'Manually'

To begin working with Circuit Playground, you will need todownload Adafruit_CircuitPlayground from our github repository (http://adafru.it/naF). (https://github.com/adafruit/Adafruit_CircuitPlayground) You can do that by visiting the github repo and manually downloading or, easier, just click this button to download the zip

Download Adafruit CircuitPlayground Library (https://github.com/adafruit/Adafruit_CircuitPlayground/archive/master.zip)
http://adafru.it/naB

Rename the uncompressed folderAdafruit_CircuitPlayground and check that
the Adafruit_CircuitPlayground folder contains Adafruit_CircuitPlayground.cpp and Adafruit_CircuitPlayground.h

Place the Adafruit_CircuitPlayground folder your arduinosketchfolder/libraries/ folder. You may need to create thelibraries subfolder if its your first library. Restart the IDE.

We also have a great tutorial on Arduino library installation at: http://learn.adafruit.com/adafruit-all-about-arduino-libraries-install-use (http://adafru.it/aYM)

© Adafruit Industries | https://learn.adafruit.com/introducing-circuit-playground | Page 29 of 37

# Run the Demo

Plug in your Circuit Playground.Under Windows you'll need to make sure you have installed the driver package (http://adafru.it/naC). Do that if you haven't!

Next, you'll also need to make sure you have installed the Adafruit Board Support package. That's required no matter what computer you're using.

## Select the Circuit Playground Board

Under the Tools -> Board submenu, scroll down toAdafruit Boards and pick Adafruit Circuit Playground

## Select the matching Port

Under Tools->Port select the port that is labed (Circuit Plaground)

© Adafruit Industries | https://learn.adafruit.com/introducing-circuit-playground | Page 30 of 37

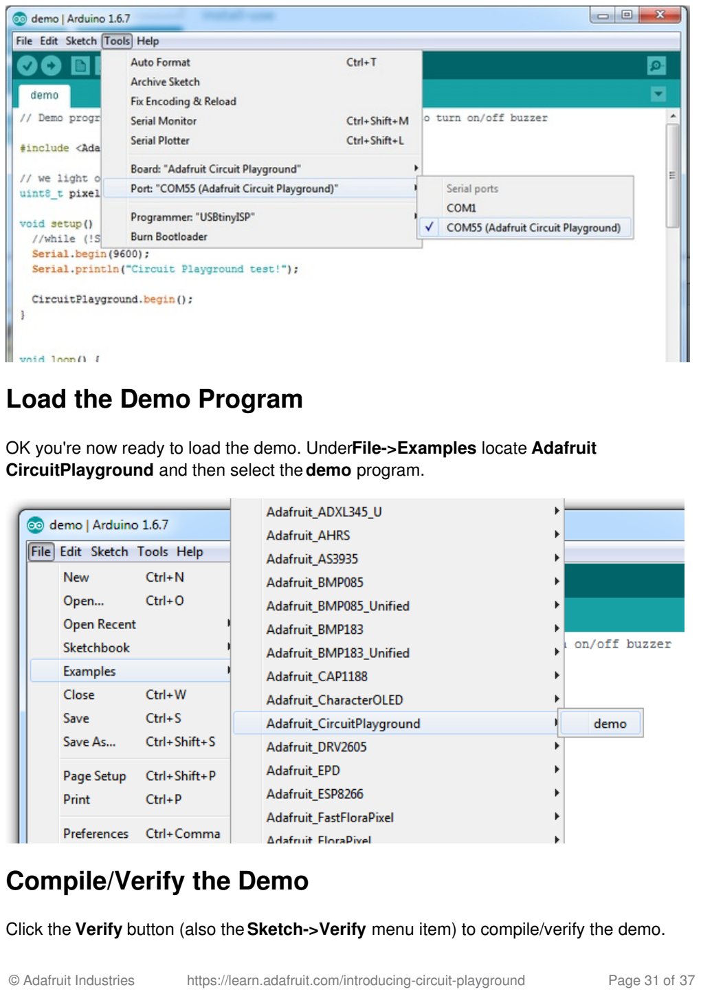
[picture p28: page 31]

## Load the Demo Program

OK you're now ready to load the demo. UnderFile->Examples locate Adafruit CircuitPlayground and then select the demo program.

## Compile/Verify the Demo

Click the Verify button (also theSketch->Verify menu item) to compile/verify the demo.

© Adafruit Industries | https://learn.adafruit.com/introducing-circuit-playground | Page 31 of 37

Make sure you get "Done compiling." and no errors

## Upload Demo

Click the Upload button to upload the code

© Adafruit Industries | https://learn.adafruit.com/introducing-circuit-playground | Page 32 of 37

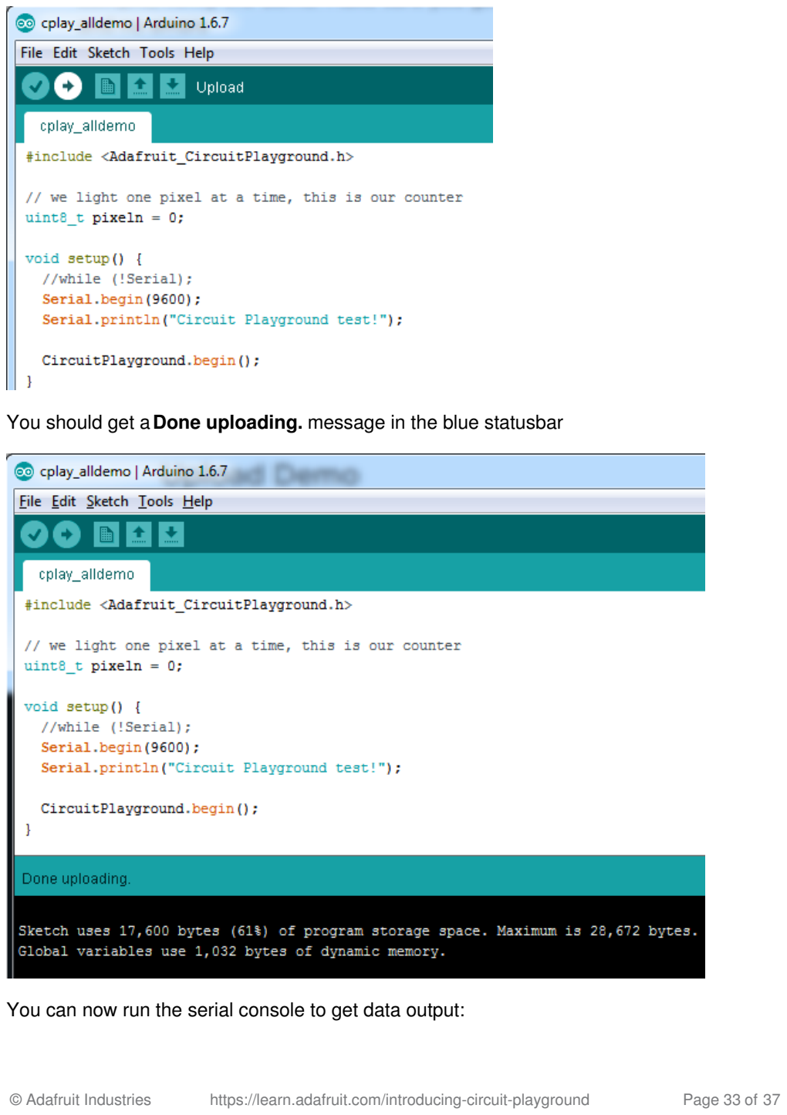
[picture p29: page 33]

You should get aDone uploading. message in the blue statusbar

You can now run the serial console to get data output:

© Adafruit Industries | https://learn.adafruit.com/introducing-circuit-playground | Page 33 of 37

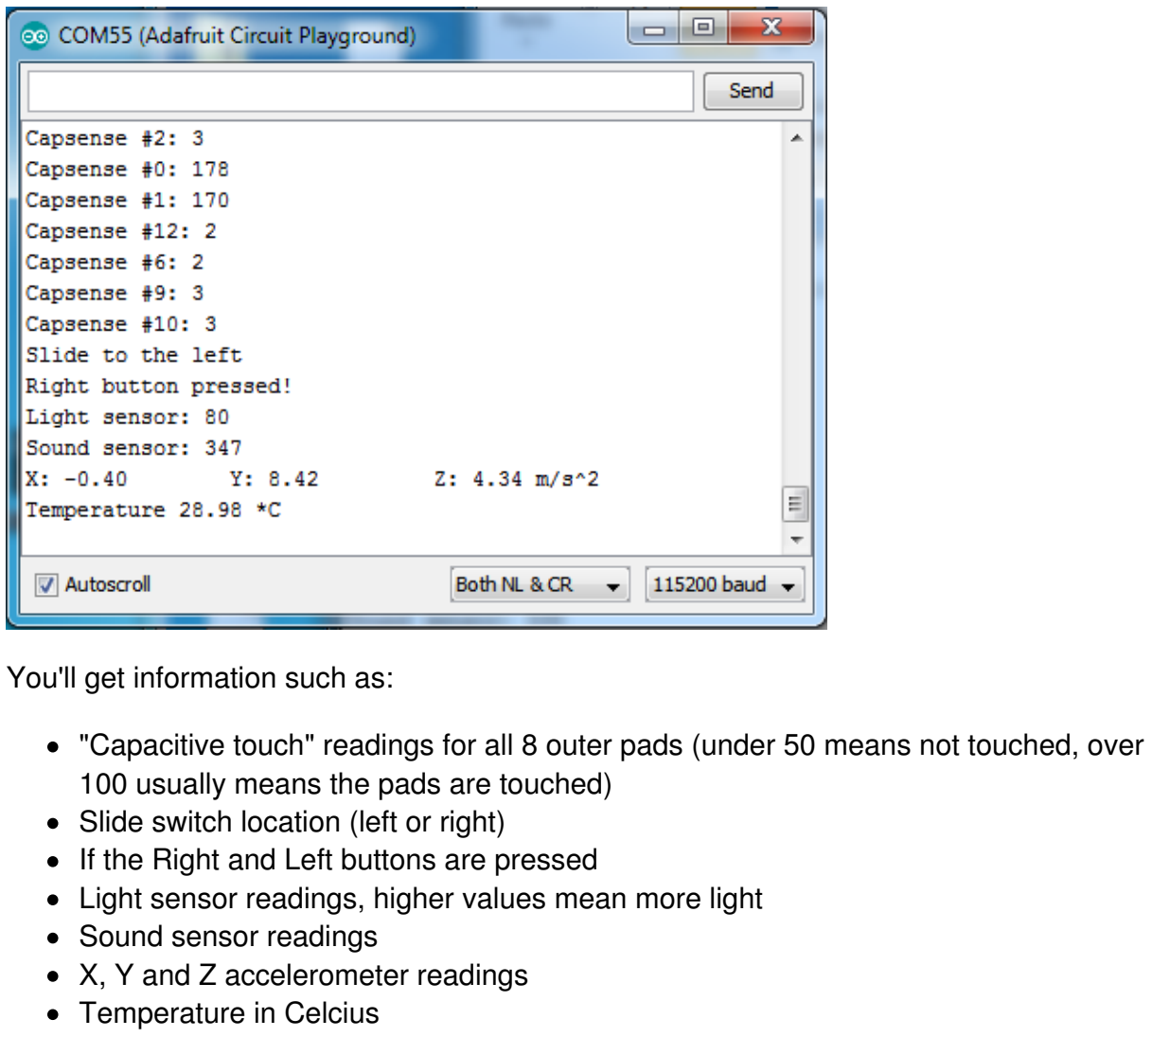
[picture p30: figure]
You'll get information such as:; 100 usually means the pads are touched) Slide switch location (left or right); Sound sensor readings X, Y and Z accelerometer readings Temperature in Celcius

"Capacitive touch" readings for all 8 outer pads (under 50 means not touched, over

If the Right and Left buttons are pressed
Light sensor readings, higher values mean more light
© Adafruit Industries | https://learn.adafruit.com/introducing-circuit-playground | Page 34 of 37

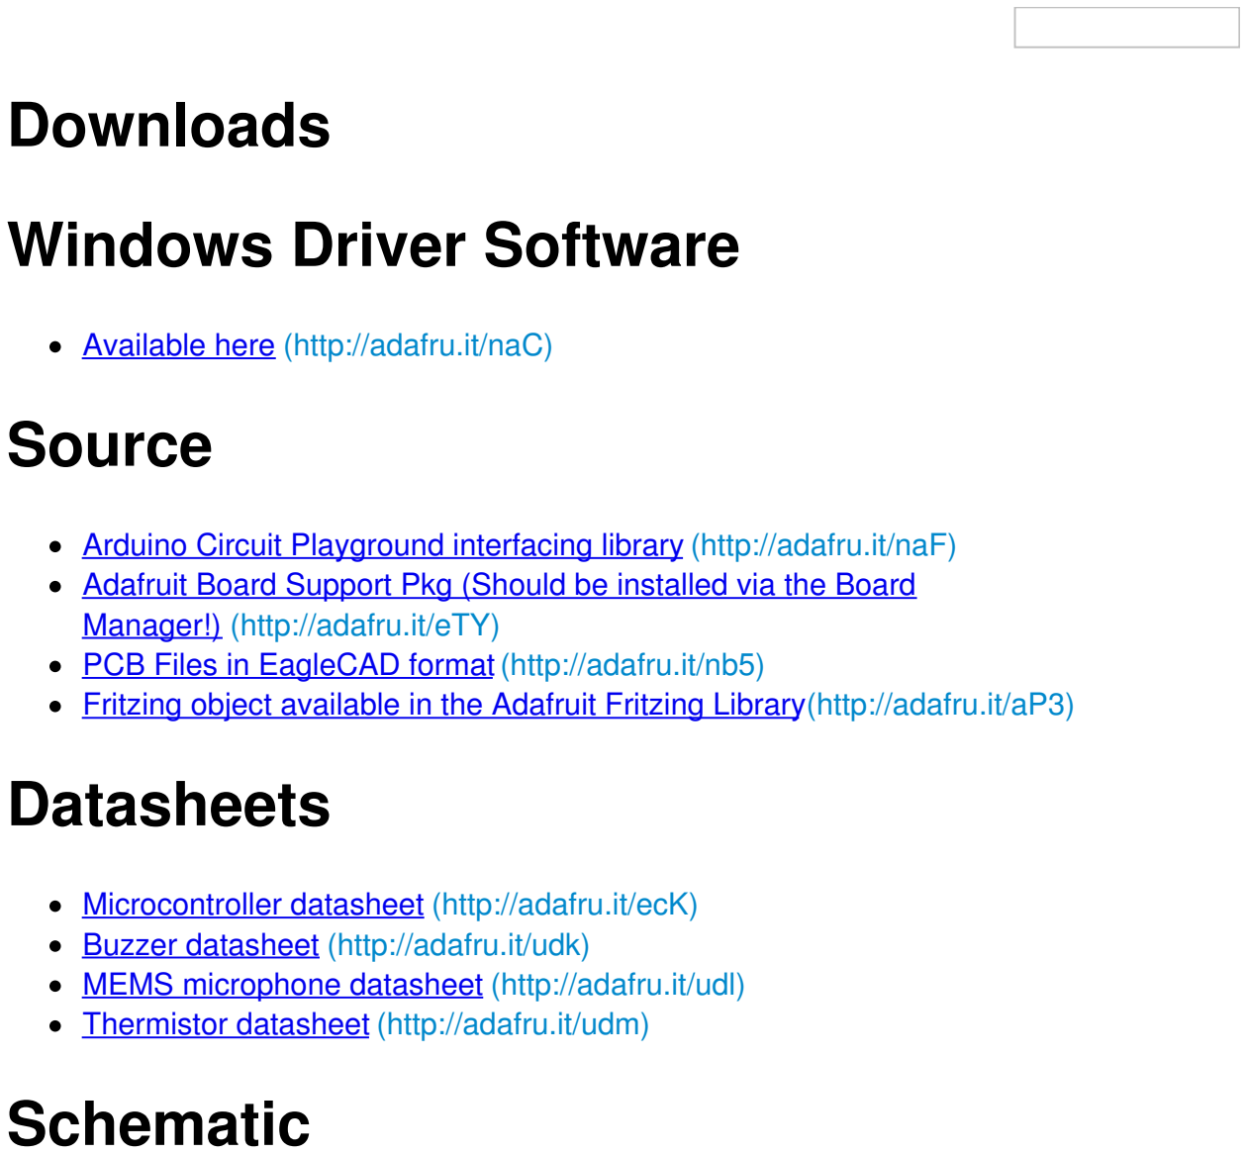
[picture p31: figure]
Downloads; Windows Driver Software; Available here (http://adafru.it/naC) Source; Manager!) (http://adafru.it/eTY); Datasheets; Microcontroller datasheet (http://adafru.it/ecK) Buzzer datasheet (http://adafru.it/udk) MEMS microphone datasheet (http://adafru.it/udl) Thermistor datasheet (http://adafru.it/udm) Schematic

Arduino Circuit Playground interfacing library (https://github.com/adafruit/Adafruit_CircuitPlayground) (http://adafru.it/naF) Adafruit Board Support Pkg (Should be installed via the Board

PCB Files in EagleCAD format (https://github.com/adafruit/Adafruit-Circuit-Playground-PCB) (http://adafru.it/nb5)
Fritzing object available in the Adafruit Fritzing Library(http://adafru.it/aP3) (https://github.com/adafruit/Fritzing-Library)
© Adafruit Industries | https://learn.adafruit.com/introducing-circuit-playground | Page 35 of 37

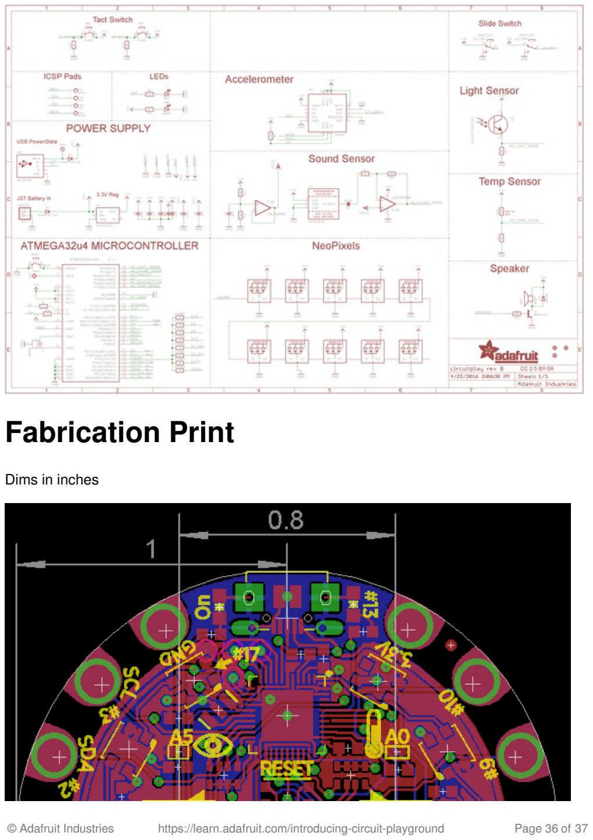
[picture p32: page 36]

# Fabrication Print

Dims in inches

© Adafruit Industries | https://learn.adafruit.com/introducing-circuit-playground | Page 36 of 37

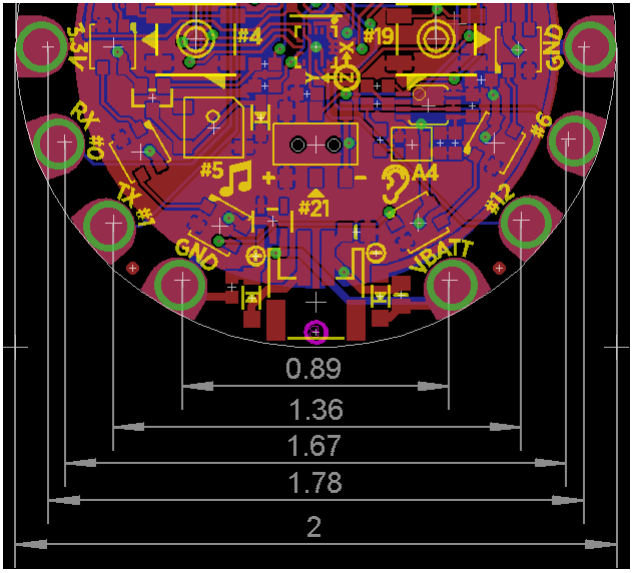
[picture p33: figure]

© Adafruit Industries | Last Updated: 2017-02-08 04:37:43 PM UTC | Page 37 of 37

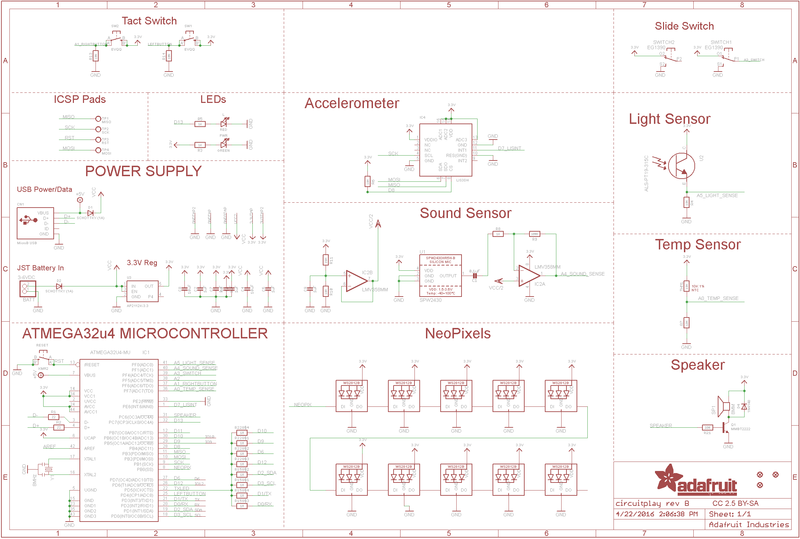
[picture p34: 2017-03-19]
img/circuit_playground_schem.png

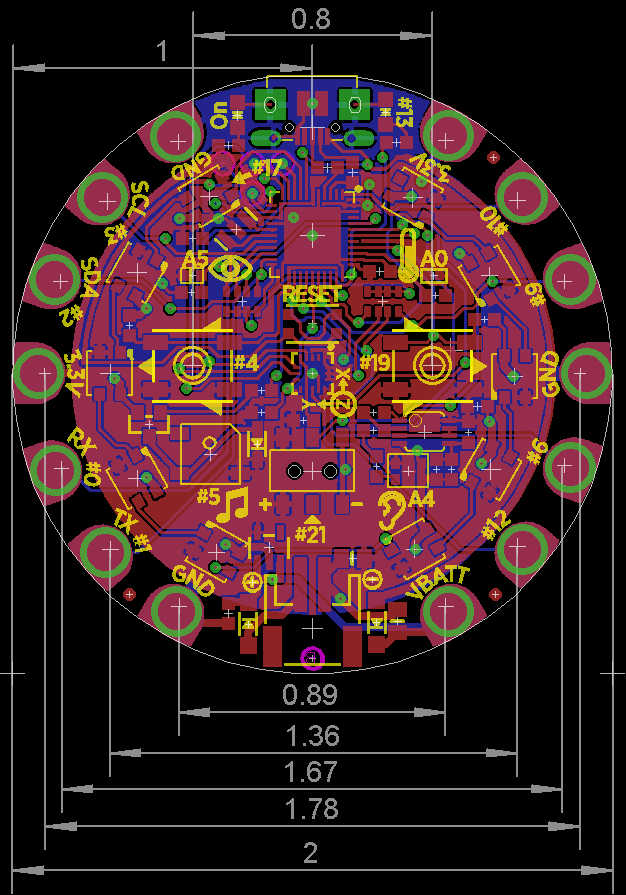
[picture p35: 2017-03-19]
img/circuit_playground_fabprint.png

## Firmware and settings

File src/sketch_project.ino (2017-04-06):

/*
 * Program Name:
 *  CS 207 (Lec 001) - Project
 *  Cyborg Headpiece (cs207-2017-project)
 *  
 * Description:
 *  A cyborg headpiece, by my definition, will be a piece of 
 *   wearable technology, affixed to the head of the wearer, 
 *   but made to look as though it is integrated into the 
 *   flesh of the wearer.
 *   
 *   This sketch will take inputs from an accelerometer and
 *    a microphone, and then react to the inputs by driving
 *    a NeoPixel Ring and NeoPixel Matrix respectively.
 * 
 * 
 * Legend:
 *  (cp)  - Adafruit Circuit Playground - Developer Edition
 *  (nps) - Adafruit NeoPixel Shield for Arduino - 40 RGB LED Pixel Matrix
 *  (npr) - Adafruit NeoPixel Ring - 24 x 5050 RGB LED
 * 
 * Setup:
 *  Connect Ext on (nps) to GND on (cp)
 *  Connect 5V on (nps) to VBATT on (cp)
 *  Connect Din on (nps) to #6 on (cp)
 *  
 *  Connect GND on (npr) to GND on (cp)
 *  Connect PWR +5V on (npr) to VBATT on (cp)
 *  Connect Data Input on (npr) to #3 on (cp)
 *  
 *  
 * Date:
 *  2017-04-05
 * 
 * Name:
 *  Richard Yeomans
 * 
 */

// Include Adafruit libraries for operation of Circuit Playground
#include <Adafruit_CircuitPlayground.h>
#include <Wire.h>
#include <SPI.h>
#include <Adafruit_NeoPixel.h>

// Serial Communication details
const int baud = 9600;

// Which pins are connected to what
const int pinShield = 6;
const int pinRing = 3;

// Stored time counts
unsigned long previousMillisCPNeoPixel;
unsigned long previousMillisShield;
unsigned long previousMillisRing;

// Motion delay thresholds
int holdCPNeoPixel;
int holdShield;
int holdRing;

// The NeoPixel on the Circuit Playground details
const int cpNeoPixelCount = 10;
int cpNeoPixel;
int cpNeoPixelColor;

// Adafruit NeoPixel Shield for Arduino - 40 RGB LED Pixel Matrix details
const int shieldRows = 8;
const int shieldCols = 5;
int shieldTotal = shieldRows * shieldCols;
Adafruit_NeoPixel shield = Adafruit_NeoPixel(shieldTotal, pinShield, NEO_GRB + NEO_KHZ800);
int shieldY;  // corresponds with rows
int shieldX;  // corresponds with cols

// Adafruit NeoPixel Ring - 24 x 5050 RGB LED details
const int ringTotal = 24;
Adafruit_NeoPixel ring = Adafruit_NeoPixel(ringTotal, pinRing, NEO_GRB + NEO_KHZ800);
int ringX;

// Mode details
boolean mode1State;
boolean mode2State;

// Mode details - Dot
int dotDirection;
boolean dotDouble;

// Sound mechanism details
const int soundSensorThresh = 339;
const int soundSensorRange = 125;
int soundSensorMax = soundSensorThresh + (soundSensorRange / 2);
int soundSensorMin = soundSensorThresh - (soundSensorRange / 2);

// Sound mechanism details - Bars
const int soundBarNeoPixelCols = shieldCols;
float soundBarNeoPixelColRatio[] = { 0.45, 0.85, 1.0, 0.85, 0.45 };
const int soundBarNeoPixelCount = shieldRows;
int soundBarNeoPixelMin = 0;
int soundBarNeoPixelMax = soundBarNeoPixelCount - 1;
float soundBarNeoPixelMid = soundBarNeoPixelMax / 2.0;

// sound bar active is used as follows:
//   0 - inactive
//   1 - active, bar goes up
//  -1 - active, bar goes down
int soundBarActive;
float soundBarRaw;
boolean soundBarPeakLoActive;
float soundBarPeakLo;
boolean soundBarPeakHiActive;
float soundBarPeakHi;
const int soundBarDropRate = 1;

// Accelerometer mechanism details
const float accelThresh = 0.5;
const float accelSensitivity = 0.03;
float accelX;  // + is force in direction towards power connector; - is force in direction towards microUSB connector
float accelY;  // + is force in direction towards pin #6 & #9; - is force in direction towards pin #0 & #2
float accelZ;  // + is force in direction below playground; - is force in direction above playground

// Accelerometer mechanism details - Dots
const int accelDotXColor = 0;
float accelDotX;
const int accelDotYColor = 85;
float accelDotY;
const int accelDotZColor = 171;
float accelDotZ;

// If this is true, debug mode is on
boolean stateDebug = false;


void setup() {
  // run once at beginning

  // prepare serial output
  Serial.begin(baud);
  Serial.println("Begin program");

  // initialize Circuit Playground
  CircuitPlayground.begin();

  // initialize NeoPixel Shield
  shield.begin();
  shield.show();  // Initialize all pixels to 'off'

  // initialize NeoPixel Ring
  ring.begin();
  ring.show();  // Initialize all pixels to 'off'

  // setting initial values for variables
  previousMillisShield = 0;
  previousMillisRing = 0;
  previousMillisCPNeoPixel = 0;
  holdShield = 300;
  holdRing = 50;
  holdCPNeoPixel = 75;

  cpNeoPixel = 0;
  cpNeoPixelColor = 0;
  shieldX = 3;
  shieldY = 0;
  ringX = 0;

  mode1State = false;
  mode2State = false;
  dotDirection = 1;
  dotDouble = false;

  soundBarActive = 0;
  soundBarRaw = soundBarNeoPixelMid;
  soundBarPeakLoActive = false;
  soundBarPeakLo = soundBarNeoPixelMid;
  soundBarPeakHiActive = false;
  soundBarPeakHi = soundBarNeoPixelMid;

  accelX = 0;
  accelY = 0;
  accelZ = 0;
  accelDotX = 0;
  accelDotY = 0;
  accelDotZ = 0;
}


void loop() {
  // run repeatedly

  // determine current time count
  unsigned long currentMillis = millis();

  // detect inputs
  boolean stateSwitch = CircuitPlayground.slideSwitch();
  boolean stateButton1 = CircuitPlayground.leftButton();
  boolean stateButton2 = CircuitPlayground.rightButton();
  int stateSoundSensor = CircuitPlayground.soundSensor();
  float stateMotionX = CircuitPlayground.motionX();
  float stateMotionY = CircuitPlayground.motionY();
  float stateMotionZ = CircuitPlayground.motionZ();

  // switch holds state, or releases state
  if (stateSwitch) {
    // check buttons
    if (stateButton1 != mode1State) {
      if (stateButton1) {
        // change direction of playground pattern
        dotDirection *= -1;
      }
    }
    if (stateButton2 != mode2State) {
      if (stateButton2) {
        // toggle double of playground pattern
        if (dotDouble) {
          dotDouble = false;
        } else {
          dotDouble = true;
        }
      }
    }

    // update mode states
    mode1State = stateButton1;
    mode2State = stateButton2;

    // run Circuit Playground NeoPixel reactor
    cpNeoPixelDisplay(currentMillis);

    // run sound reactor
    shieldDisplay(currentMillis, stateSoundSensor);

    // run accelerometer reactor
    ringDisplay(currentMillis, stateMotionX, stateMotionY, stateMotionZ);
  }


/*
  // debuging code for displays
  if (stateDebug) {
    int pixel = 0;

    if (stateSwitch) {
      pixel = 5;
    }

    CircuitPlayground.clearPixels();
    CircuitPlayground.setPixelColor(pixel, CircuitPlayground.colorWheel(0));
  }
*/

  // send message to serial output
  if (stateDebug) {
    // accelerometer details
    Serial.println();
    Serial.print("Switch: ");
    Serial.print(stateSwitch);
    Serial.print("  But 1: ");
    Serial.print(stateButton1);
    Serial.print("  But 2: ");
    Serial.println(stateButton2);

    delay(120);
  }
}


void cpNeoPixelDisplay(unsigned long currentMillis) {
  // update Circuit Playground NeoPixels

  // change NeoPixel to illuminate
  if (currentMillis - previousMillisCPNeoPixel > holdCPNeoPixel) {
    previousMillisCPNeoPixel = currentMillis;

    cpNeoPixel += dotDirection;
    if (cpNeoPixel < 0) {
      cpNeoPixel += cpNeoPixelCount;
    }
    if (cpNeoPixel >= cpNeoPixelCount) {
      cpNeoPixel -= cpNeoPixelCount;
    }
  }

  // change colour of NeoPixel
  cpNeoPixelColor++;
  if (cpNeoPixelColor >= 255) {
    cpNeoPixelColor = 0;
  }

  // update NeoPixels
  CircuitPlayground.clearPixels();
  CircuitPlayground.setPixelColor(cpNeoPixel, CircuitPlayground.colorWheel(cpNeoPixelColor));
  if (dotDouble) {
    CircuitPlayground.setPixelColor(cpNeoPixelCount - cpNeoPixel - 1, CircuitPlayground.colorWheel(cpNeoPixelColor));
  }
}


int shieldPixel(int row, int col) {
  // return the NeoPixel number for the desired row and col
  // remember that row 0 is first row, and col 0 is first col
  int pixel = (col * shieldRows) + row;
  return pixel;
}

void shieldDisplay(unsigned long currentMillis, int valueRaw) {
  // update shield display based on sound sensor value

  // map raw value to sound bar raw value
  soundBarRaw = float(soundBarNeoPixelMax - soundBarNeoPixelMin) / float(soundSensorMax - soundSensorMin) * float(valueRaw - soundSensorMin) + float(soundBarNeoPixelMin);

  // if sound bar raw value is outside range, limit
  soundBarRaw = constrain(soundBarRaw, soundBarNeoPixelMin - (soundBarNeoPixelCount / 2), soundBarNeoPixelMax + (soundBarNeoPixelCount / 2));

  // decide if live bar should show something
  //  0 - no bar
  //  1 - bar above middle
  // -1 - bar below middle
  float soundBarActiveTest = (soundBarRaw - soundBarNeoPixelMid) * 10.0;
  if (abs(soundBarActiveTest) < 10) {
    soundBarActive = 0;
  } else {
    soundBarActive = abs(soundBarActiveTest) / soundBarActiveTest;
  }

  // slowly drop peak bars towards middle
  if (currentMillis - previousMillisShield > holdShield) {
    previousMillisShield = currentMillis;

    soundBarPeakLo += soundBarDropRate;
    if (soundBarPeakLo > soundBarNeoPixelMid) {
      soundBarPeakLo = soundBarNeoPixelMid;
      soundBarPeakLoActive = false;
    }

    soundBarPeakHi -= soundBarDropRate;
    if (soundBarPeakHi < soundBarNeoPixelMid) {
      soundBarPeakHi = soundBarNeoPixelMid;
      soundBarPeakHiActive = false;
    }
  }

  // if live bar is active, update appropriate peak bar, if necessary
  if (soundBarActive != 0) {
    if (soundBarActive > 0) {
      soundBarPeakHi = max(soundBarPeakHi, soundBarRaw);
      soundBarPeakHiActive = true;
    } else {
      soundBarPeakLo = min(soundBarPeakLo, soundBarRaw);
      soundBarPeakLoActive = true;
    }
  }

  // draw bars on shield
  for (int i = 0; i < soundBarNeoPixelCols; i++) {
    float ratio = soundBarNeoPixelColRatio[i];
    float ratioPeakLo = (soundBarPeakLo - soundBarNeoPixelMid) * ratio + soundBarNeoPixelMid;
    float ratioPeakHi = (soundBarPeakHi - soundBarNeoPixelMid) * ratio + soundBarNeoPixelMid;
    float ratioRaw = (soundBarRaw - soundBarNeoPixelMid) * ratio + soundBarNeoPixelMid;

    for (int j = 0; j < soundBarNeoPixelCount; j++) {
      // set default colour to black
      int pickColor = 0;

      // if within peak bar ranges, change to peak colour
      if (soundBarPeakLoActive) {
        if ((j >= ratioPeakLo) && (j < soundBarNeoPixelMid)) {
          pickColor = 1;
        }
      }
      if (soundBarPeakHiActive) {
        if ((j <= ratioPeakHi) && (j > soundBarNeoPixelMid)) {
          pickColor = 1;
        }
      }

      // if within live bar range, change to live colour
      if (soundBarActive != 0) {
        if (soundBarActive > 0) {
          if ((j <= ratioRaw) && (j > soundBarNeoPixelMid)) {
            pickColor = 2;
          }
        } else {
          if ((j >= ratioRaw) && (j < soundBarNeoPixelMid)) {
            pickColor = 2;
          }
        }
      }

      int soundBarNeoPixelColorR;
      int soundBarNeoPixelColorG;
      int soundBarNeoPixelColorB;
      switch (pickColor) {
        case 1:  // red
          soundBarNeoPixelColorR = 63;
          soundBarNeoPixelColorG = 0;
          soundBarNeoPixelColorB = 0;
          break;
        case 2:  // green
          soundBarNeoPixelColorR = 0;
          soundBarNeoPixelColorG = 255;
          soundBarNeoPixelColorB = 0;
          break;
        default:  // black
          soundBarNeoPixelColorR = 0;
          soundBarNeoPixelColorG = 0;
          soundBarNeoPixelColorB = 0;
          break;
      }

      // update NeoPixel colour (does not update shield immediately)
      int pixel = shieldPixel(j, i);
      shield.setPixelColor(pixel, soundBarNeoPixelColorR, soundBarNeoPixelColorG, soundBarNeoPixelColorB);
    }
  }

  // update shield
  shield.show();
}


void ringDisplay(unsigned long currentMillis, float valueX, float valueY, float valueZ) {
  // update ring display based on accelerometer values

  // slow down the movements
  if (currentMillis - previousMillisRing > holdRing) {
    previousMillisRing = currentMillis;

    // turn off dots
    ring.setPixelColor(accelX, 0, 0, 0);
    ring.setPixelColor(accelY, 0, 0, 0);
    ring.setPixelColor(accelZ, 0, 0, 0);

    // accelerometer values are greater than threshold, move dot
    if (abs(valueX) > accelThresh) {
      accelX += valueX * accelSensitivity;

      if (accelX < 0) {
        accelX += ringTotal;
      }
      if (accelX > ringTotal) {
        accelX -= ringTotal;
      }
    }
    if (abs(valueY) > accelThresh) {
      accelY += valueY * accelSensitivity;

      if (accelY < 0) {
        accelY += ringTotal;
      }
      if (accelY > ringTotal) {
        accelY -= ringTotal;
      }
    }
    if (abs(valueZ) > accelThresh) {
      accelZ += valueZ * accelSensitivity;

      if (accelZ < 0) {
        accelZ += ringTotal;
      }
      if (accelZ > ringTotal) {
        accelZ -= ringTotal;
      }
    }
  }

  // find integers from tracked values
  int dotX = accelX;
  int dotY = accelY;
  int dotZ = accelZ;

  // in case of overlapping, add colours together
  if (dotX == dotY) {
    if (dotX == dotZ) {
      ring.setPixelColor(dotX, 255, 255, 255);
    } else {
      ring.setPixelColor(dotX, 255, 0, 255);
      ring.setPixelColor(dotZ, 0, 255, 0);
    }
  } else {
    if (dotX == dotZ) {
      ring.setPixelColor(dotX, 255, 255, 0);
      ring.setPixelColor(dotY, 0, 0, 255);
    } else {
      if (dotY == dotZ) {
        ring.setPixelColor(dotX, 255, 0, 0);
        ring.setPixelColor(dotY, 0, 255, 255);
      } else {
        ring.setPixelColor(dotX, 255, 0, 0);
        ring.setPixelColor(dotY, 0, 0, 255);
        ring.setPixelColor(dotZ, 0, 255, 0);
      }
    }
  }

  // update ring
  ring.show();
}

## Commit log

2017-02-05 Fixed a couple more errors in README file
    This is to fix a couple more errors I found in README file.
2017-03-18 deleting file as it is not in correct location
    deleting file as it is not in correct location
    [sketch_project.ino]
2017-03-18 uploading initial test sketch
    uploading initial test sketch. Just some experimental code to test sound sensor and NeoPixels
2017-03-19 More work on sound sensor detection
    More work on sound sensor detection. I suspect it works like a photo resistor, having a logarithmic scale.
2017-03-19 Uploading image of progress with Circuit Playground
    Uploading image of progress with Circuit Playground.
2017-03-19 Circuit Diagram for Circuit Playground
    Circuit Diagram for Circuit Playground.
2017-03-19 Fabrication Schematic for Circuit Playground
    Fabrication Schematic for Circuit Playground.
2017-03-19 Datasheet for ATmega32U4
    Datasheet for ATmega32U4, the microprocessor in the Circuit Playground.
2017-03-19 Introducing Circuit Playground
    Introducing Circuit Playground, a simple guide overviewing the Circuit Playground.
2017-03-19 Significant updates to bill of materials
    Significant updates to bill of materials.
2017-03-19 Added manufacturer information to materials
    Added manufacturer information to materials
2017-03-19 Added reference to Adafruit downloads for Circuit Playground
    Added reference to Adafruit downloads for Circuit Playground
2017-04-03 Mature sound reactor code
    Mature sound reactor code. I'm satisfied with how this code works, moving on to accelerometer reactor.
2017-04-03 Basic test code for accelerometer
    Basic test code for accelerometer
2017-04-03 Mature accelerometer reactor
    Mature accelerometer reactor. Time to start physically assembling this piece.
2017-04-03 Added features for buttons and switch
    Added features for buttons and switch
2017-04-06 Fixed pins, as I moved things around while sewing
    Fixed pins, as I moved things around while sewing
    [sketch_project.ino]
2017-04-06 Tweaking thresholds and ranges for sound sensor
    Tweaking thresholds and ranges for sound sensor
2017-04-08 Adding Fritzing diagrams
    Adding Fritzing diagrams
    [Project_Cyborg-Headpiece.fzz]
